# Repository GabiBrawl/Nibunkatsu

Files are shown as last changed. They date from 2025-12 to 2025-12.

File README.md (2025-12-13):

# Nibunkatsu One ✦ にぶんかつ
### A Split Mechanical Keyboard Built with Hack Club Blueprint

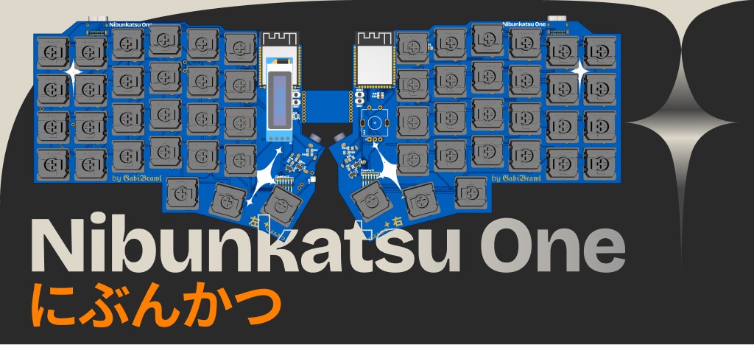
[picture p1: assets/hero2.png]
Nibunkatsu One


> にぶんかつ ✦ Nibunkatsu comes from the Japanese word for splitting in half.

Nibunkatsu is a compact split keyboard for typing and programming. I'll be using the ESP32-S3 microcontroller with KMK firmware, featuring RGB under the keys, an OLED display on the left half, and a rotary encoder in the right half!!

This project was created as part of the [Hack Club Blueprint](https://blueprint.hackclub.com) program that empowers high school students to design and build real hardware projects.

**Project Stats:** ~70 hours over the course of 1 week of active work and learning!

---

## Features

- **Split Design** — 5x7 layout per half, including a number row
- **RGB Underglow** — 28 individually addressable WS2812C LEDs per half
- **OLED Display** — 0.91" display for layer status and other keyboard info
- **Rotary Encoder** — PEC11 encoder for volume control and maybe more?
- **Hotswap Sockets** — Simple switch replacement without constant soldering
- **KMK Firmware** — Programmable using Python
- **TRRS Connection** — A 3.5mm audio cable for split communication between both halves. Also with ESD protection, protecting the MCU's TX/RX pins.

## Repository Structure

```
├── firmware/     - KMK firmware code and configuration
├── PCB/          - EasyEDA PCB project files and schematics
├── CAD/          - 3D models for the keyboard case and plates (.3mf and .step)
└── assets/       - Work screenshots and photos 
├── bom.csv       - Bill of Materials with supplier links, prices and quantities
```

---

## Hardware Specifications

### Core Components
- **Microcontroller:** ESP32-S3-WROOM-1-N4R2
- **Switches:** Cherry MX compatible hotswap sockets (I'll be personally using Gateron Banana low profile switches)
- **RGB LEDs:** WS2812C-2020
- **Display:** 0.91" OLED (128×32 pixels)
- **Encoder:** PEC11 rotary encoder with 24 steps and push button
- **Connection:** TRRS cable for communication between halves

### Case & Mounting
The case was designed in Shapr3D with 4 printable models:
- Left case + Left plate
- Right case + Right plate

Bo th available in `.3mf` and `.step` formats positioned in the [`CAD/`](CAD/) directory!

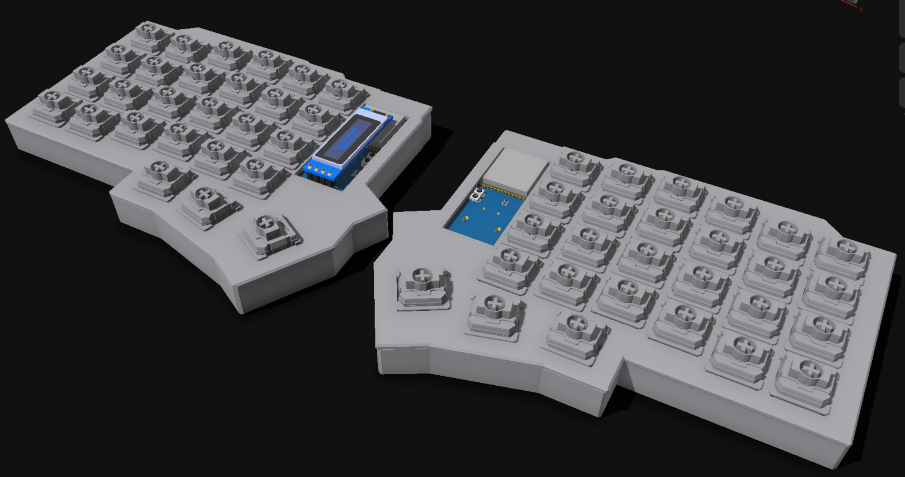
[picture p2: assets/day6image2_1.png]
3D Case Model


---

## Keymap

3-layer configuration:

- **Layer 0 (Base):** QWERTY layout with a number row
- **Layer 1 (Shortcuts):** Some operating system shortcuts maybe
- **Layer 2 (Navigation):** Arrow keys and media controls

## Firmware

Written in Python using the [KMK firmware framework](https://github.com/KMKfw/kmk_firmware).

The firmware source code is available in [`firmware/`](firmware/).

---

## Bill of Materials

**Total cost:** €153.11

| Component Type | Part Name | Qty | Other Notes |
| :--- | :--- | :--- | :--- |
| **Microcontroller** | ESP32-S3-WROOM-1-N4R2 | 3 | MCU |
| **Switches** | Gateron Low Profile (Banana) | 54 | Tactile yet silent |
| **Keycaps** | PBT Low Profile | 1 | Double-shot PBT, getting shine-through letters |
| **PCB Fabrication** | Custom PCB | 5 | via JLCPCB |
| **RGB LEDs** | WS2812C-2020 | 55 | Per-key RGB underglow |
| **Connectivity** | TRRS Cable | 1 | Interconnect cable |
| **Sockets** | Kailh Hot-Swap Sockets | 100 | Solder-free switch replacement |
| **Display** | 0.91" OLED | 1 | 128×32 pixel status display |
| **Controls** | PEC11 Rotary Encoder | 1 | Volume control |
| **Misc Electronics** | Diodes, Capacitors, LDOs, Resistors | ~150 | Logic, power regulation, ESD protection |

The complete CSV with supplier links is available here: [`bom.csv`](bom.csv)

---

## License

This project uses a three-part licensing model to appropriately protect hardware, software, and documentation.

| Component | License | Covers |
| :--- | :--- | :--- |
| **Hardware** | [CERN-OHL-W-2.0](LICENSE-hardware) | PCB designs, schematics, mechanical CAD files |
| **Firmware** | [MIT License](LICENSE-firmware) | Python/KMK firmware and source code |
| **Documentation** | [CC BY-SA 4.0](LICENSE-assets) | Assets, photos, diagrams, written guides |

### Why Three Licenses?

- **Hardware (CERN OHL):** Covers physical manufacturing rights and ensures attribution for derivative designs
- **Firmware (MIT):** Permissive software license allowing easy reuse and integration
- **Assets (CC BY-SA):** Ensures proper attribution for media assets and documentation

> **Note:** Third-party project dependencies may have different licenses. Please refer to their respective repositories for licensing information.

---

## Acknowledgments

Designed with 💙 by 𝕲𝕭

Special thanks to the Hack Club community for their support!

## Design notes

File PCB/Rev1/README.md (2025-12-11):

# Revision 1
This is the first revision of the PCB design for Nibunkatsu One.

You can check the [Schematic PDF here](./other%20assets/Nibunkatsu_One_Rev1_Schematics.pdf), and the [PCB PDF here](./other%20assets/Nibunkatsu_One_Rev1_PCB.pdf).

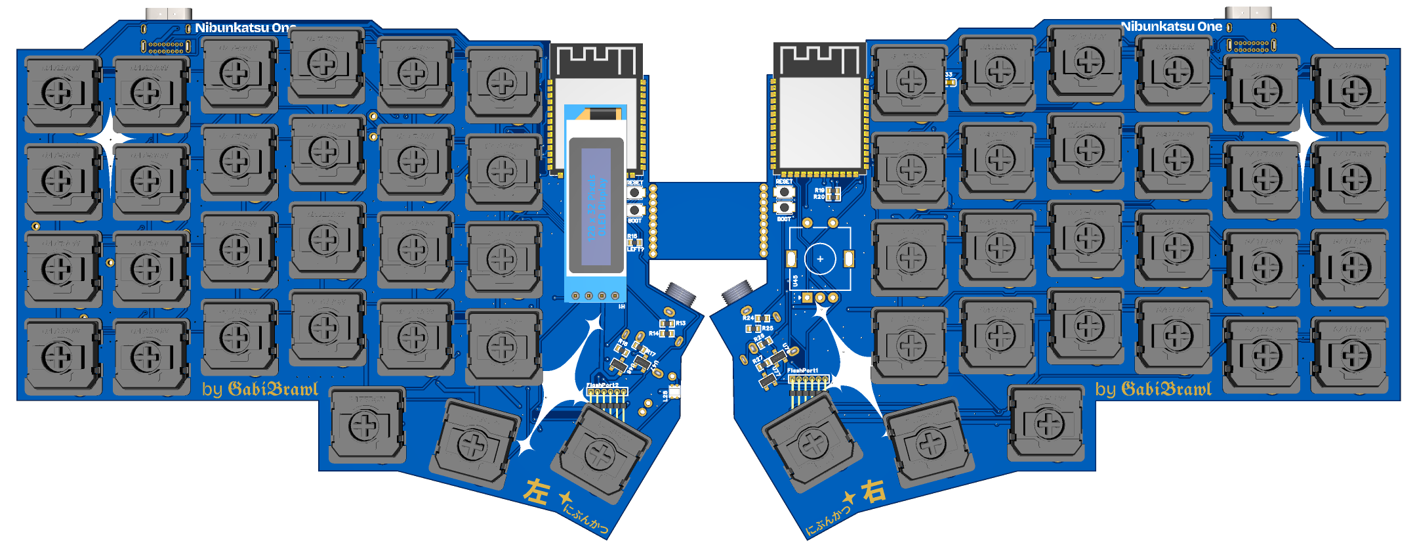
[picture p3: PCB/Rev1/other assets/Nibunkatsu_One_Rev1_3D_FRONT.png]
PCB Rev1 3D PCB Front

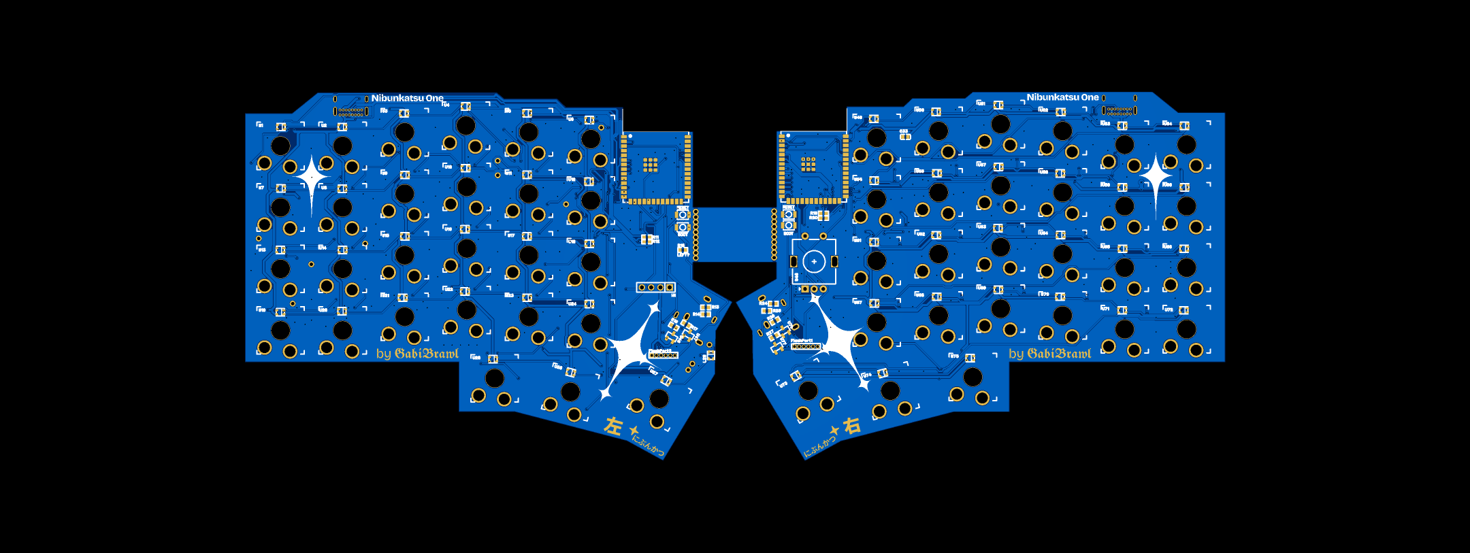
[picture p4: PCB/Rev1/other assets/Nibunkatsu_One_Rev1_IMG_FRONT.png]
PCB Rev1 PCB Front

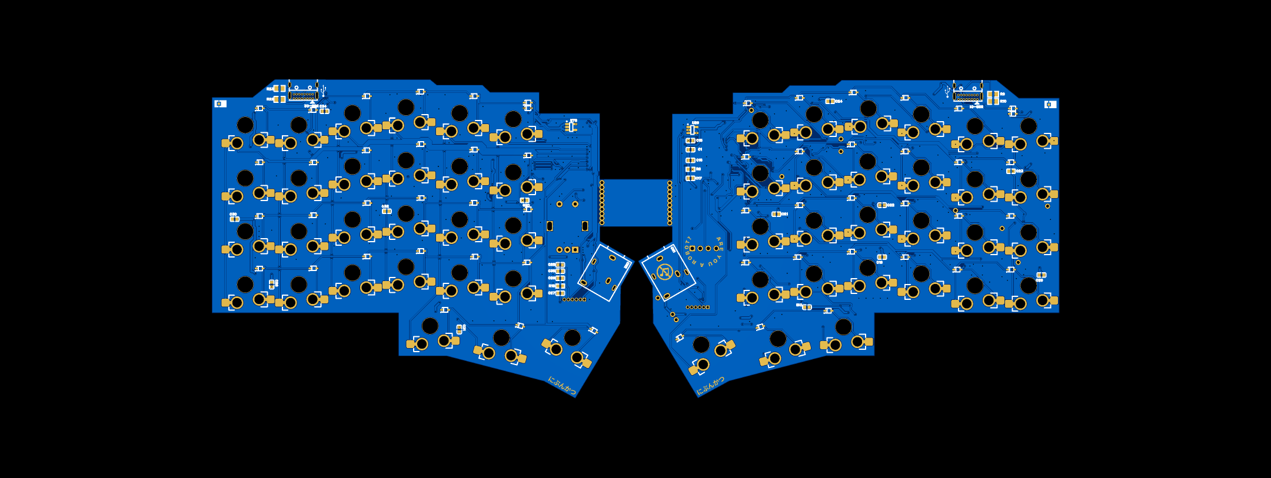
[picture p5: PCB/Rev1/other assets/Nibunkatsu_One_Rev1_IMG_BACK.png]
PCB Rev1 PCB Back


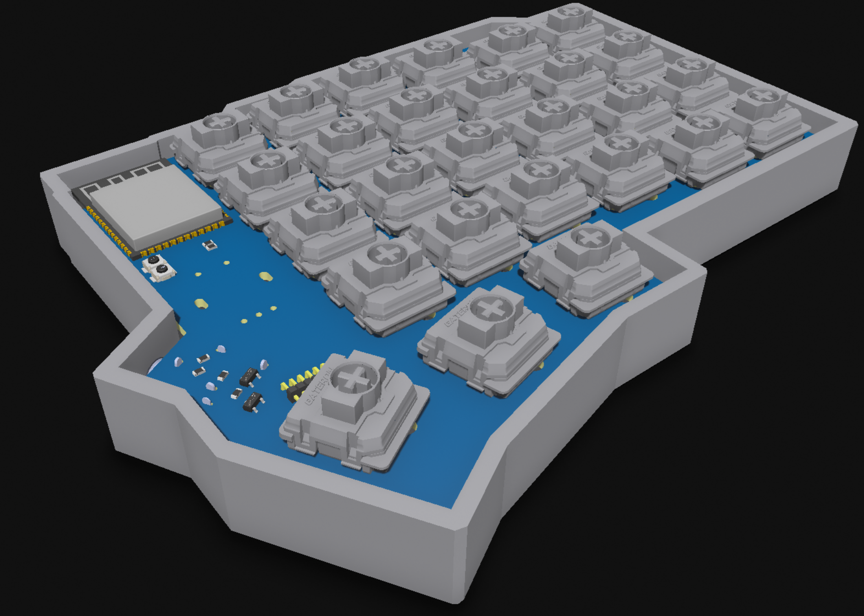
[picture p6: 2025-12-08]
assets/day5image6.png

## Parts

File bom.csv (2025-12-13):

Component Type | Comment | Quantity | Manufacturer Part | Unit Cost (Cost) | Total Cost (Cost)
MCU | ESP32-S3-WROOM-1-N4R2 | 3 | ESP32-S3-WROOM-1-N4R2 | 4.37 | 13.11 | https://www.digikey.pt/en/products/detail/espressif-systems/ESP32-S3-WROOM-1-N4/16162639
LED/Lighting | WS2812C-2020 | 55 | WS2812C-2020 | 0.15 | 11.61 | https://pt.aliexpress.com/item/32878302621.html
Diode | 1N4148WS | 60 | 1N4148WS | 0.057 | 3.42 | https://www.digikey.pt/en/products/detail/onsemi/1N4148WS/1873805
Diode | BAT54S | 5 | BAT54S | 0.11 | 0.55 | https://www.digikey.pt/en/products/detail/diotec-semiconductor/BAT54S/13164121
Switch | SW_Gateron_LowProfile_HotSwap_PTH1 | 54 | N/A | 0.4 | 31 | https://www.gateron.co/products/gateron-low-profile-mechanical-switch-set?variant=40557145784409
Switch | B3U-1000P | 5 | B3U-1000P | 0.81 | 4.05 | https://www.digikey.pt/en/products/detail/omron-electronics-inc-emc-div/B3U-1000P/1534338
Encoder | PEC11 | 1 | N/A | 1.9 | 1.9 | https://www.digikey.pt/en/products/detail/bourns-inc/PEC11R-4220F-S0024/4499660
Connector/Jack | PJ-324M | 2 | PJ-324M | 0.45 | 6.24 | https://pt.aliexpress.com/item/1005010212164993.html
Connector | USB4085-GF-A | 2 | USB4085-GF-A | 0.76 | 1.52 | https://www.digikey.pt/en/products/detail/gct/USB4085-GF-A/9859662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
Power Management | AP2112K-3.3TRG1 | 3 | AP2112K-3.3TRG1 | 0.35 | 1.05 | https://www.digikey.pt/en/products/detail/diodes-incorporated/AP2112K-3-3TRG1/4470746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
Capacitor | 1nF | 4 | N/A | 0.3 | 1.2 | https://www.digikey.pt/en/products/detail/kemet/C0603X102K5RAC3316/10315783
Capacitor | 1uF | 4 | N/A | 0.07 | 0.28 | https://www.digikey.pt/en/products/detail/samsung-electro-mechanics/CL10B105KP8NNNC/3887604
Capacitor | 0.1uF | 4 | N/A | 0.07 | 0.28 | https://www.digikey.pt/en/products/detail/kemet/C0603C104K5RACTU/1465594
Capacitor | 22uF | 4 | N/A | 0.07 | 0.28 | https://www.digikey.pt/en/products/detail/samsung-electro-mechanics/CL10A226MP8NUNE/3886932
Capacitor | 10uF | 8 | N/A | 0.07 | 0.56 | https://www.digikey.pt/en/products/detail/samsung-electro-mechanics/CL10A106KP8NNNC/3886850
Capacitor | 100nF | 20 | N/A | 0.125 | 2.5 | https://www.digikey.pt/en/products/detail/samsung-electro-mechanics/CL10E104KC8VPNC/20498486
Resistor | 10K | 8 | N/A | 0.09 | 0.72 | https://www.digikey.pt/en/products/detail/yageo/RC0603FR-0710KL/726880
Resistor | 22 | 8 | N/A | 0.12 | 0.96 | https://www.digikey.pt/en/products/detail/rohm-semiconductor/ESR03EZPJ220/1983463
Display | 0.91 inch oled white | 1 |  | 3.87 | 3.87 | https://pt.aliexpress.com/item/1005008918700196.html
Keycaps | MX Low Profile | 1 |  | 25.18 | 25.18 | https://pt.aliexpress.com/item/1005008279484599.html
Kailh Hotswap Sockets | 50 pack | 2 |  | 7.95 | 15.9 | https://splitkb.com/products/kailh-hotswap-sockets
TRRS Cable |  | 1 |  | 2.65 | 2.65 | https://pt.aliexpress.com/item/1005009181119614.html
3D Prints | 2 case sides of the keyboard and 2 plates | 1 |  |  | 0
PCB |  | 1 |  | 24.28 | 24.28
 |  |  |  | Grand Total: | 153.11

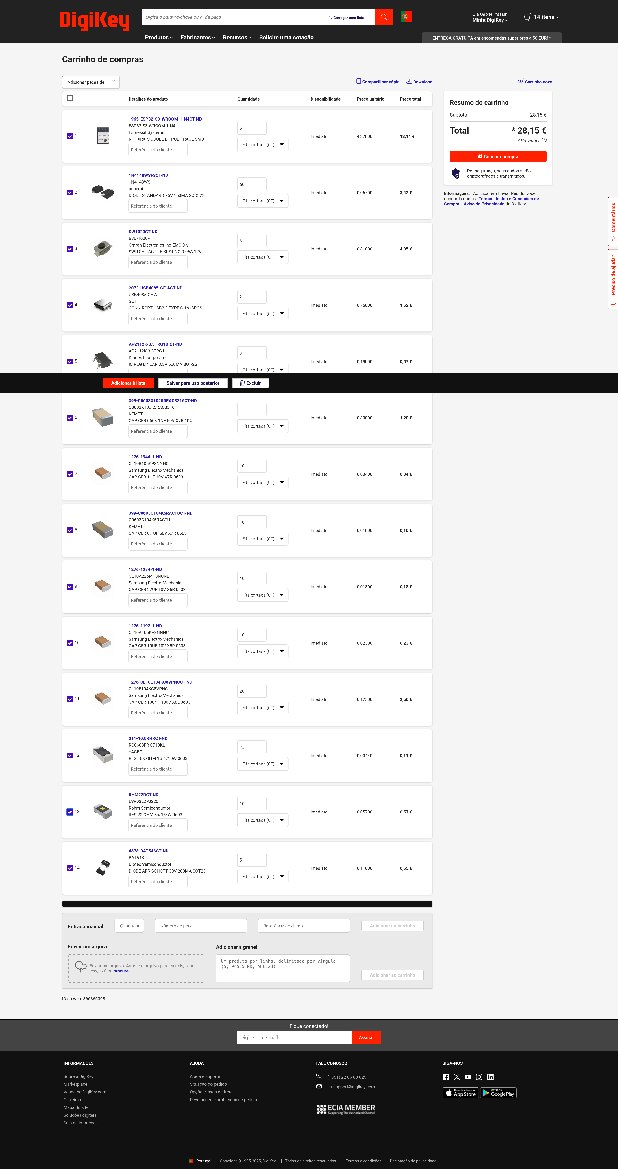
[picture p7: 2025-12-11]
assets/Shopping Cart Screenshots/DigiKey.png

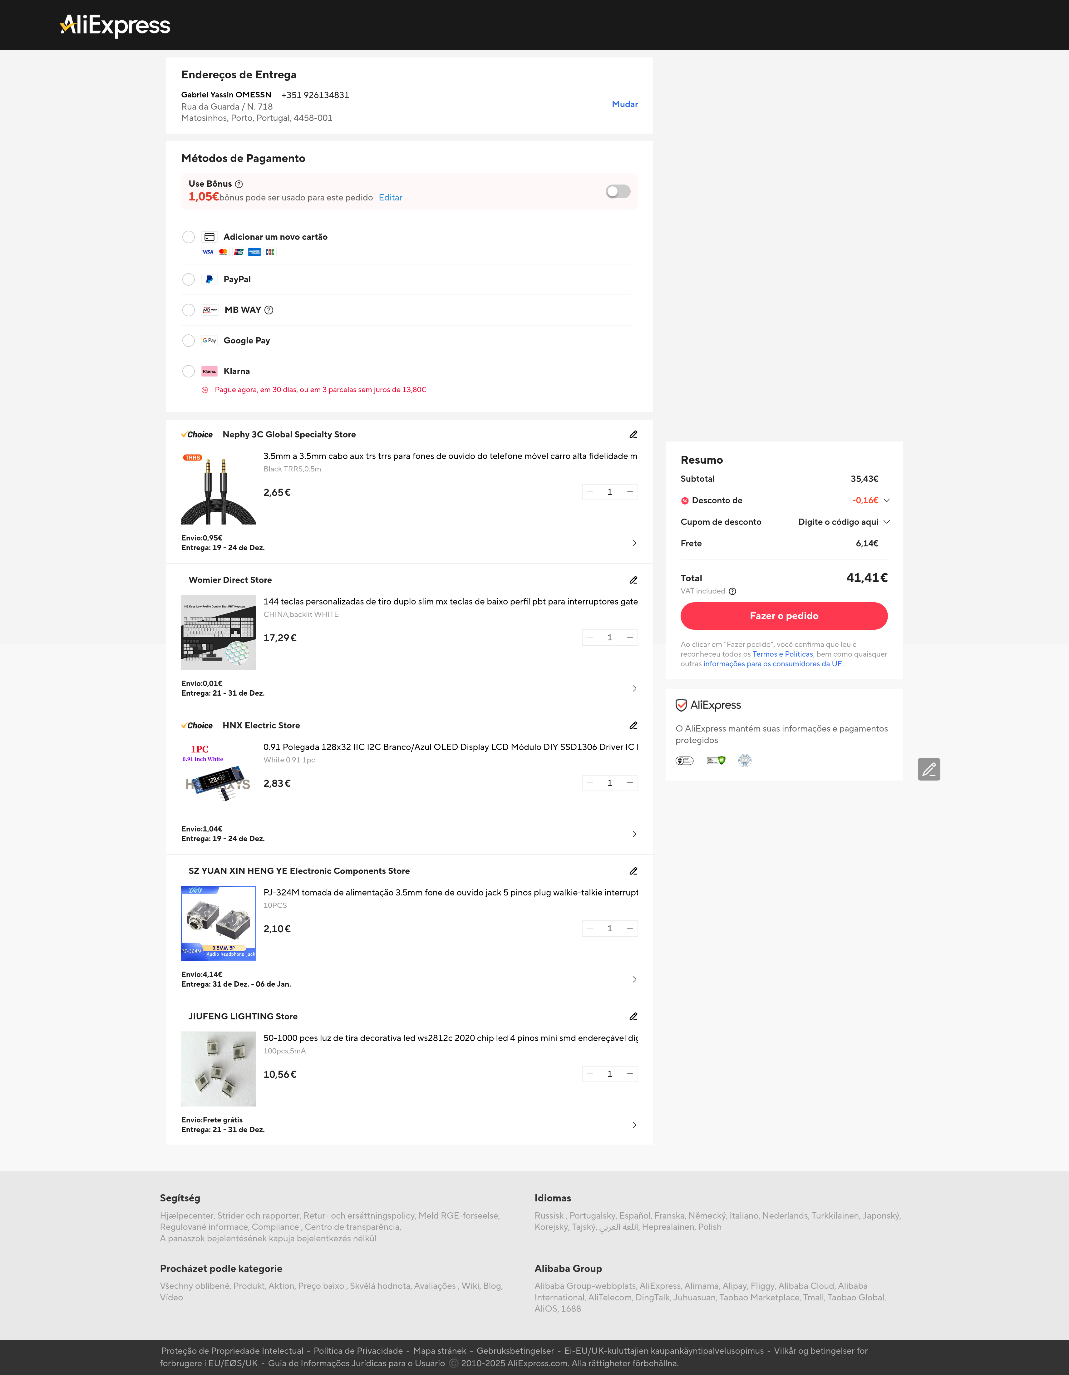
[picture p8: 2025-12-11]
assets/Shopping Cart Screenshots/AliExpress.png

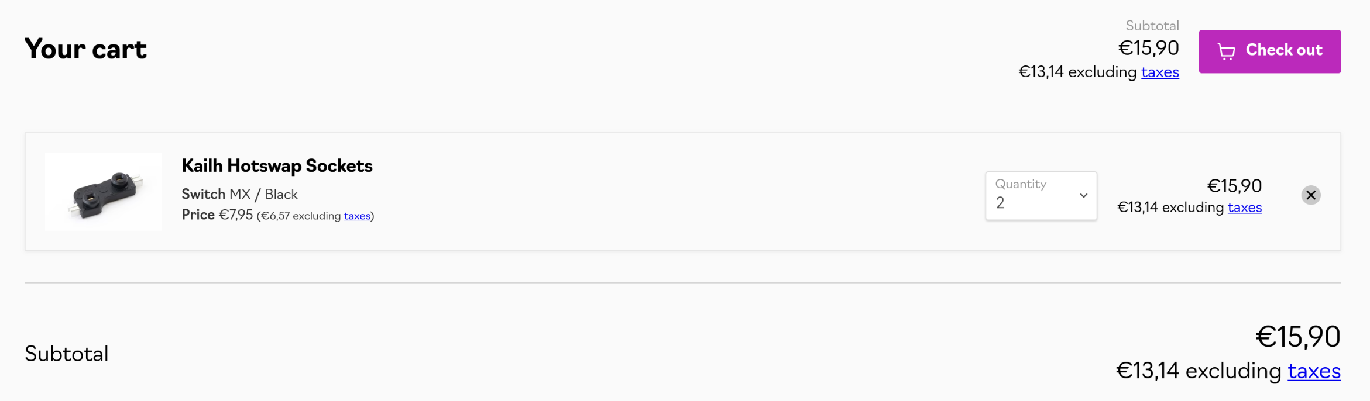
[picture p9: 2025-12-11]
assets/Shopping Cart Screenshots/Splitkb.png

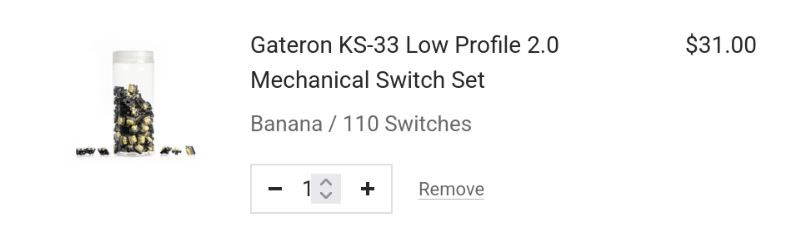
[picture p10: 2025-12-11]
assets/Shopping Cart Screenshots/Gateron.png

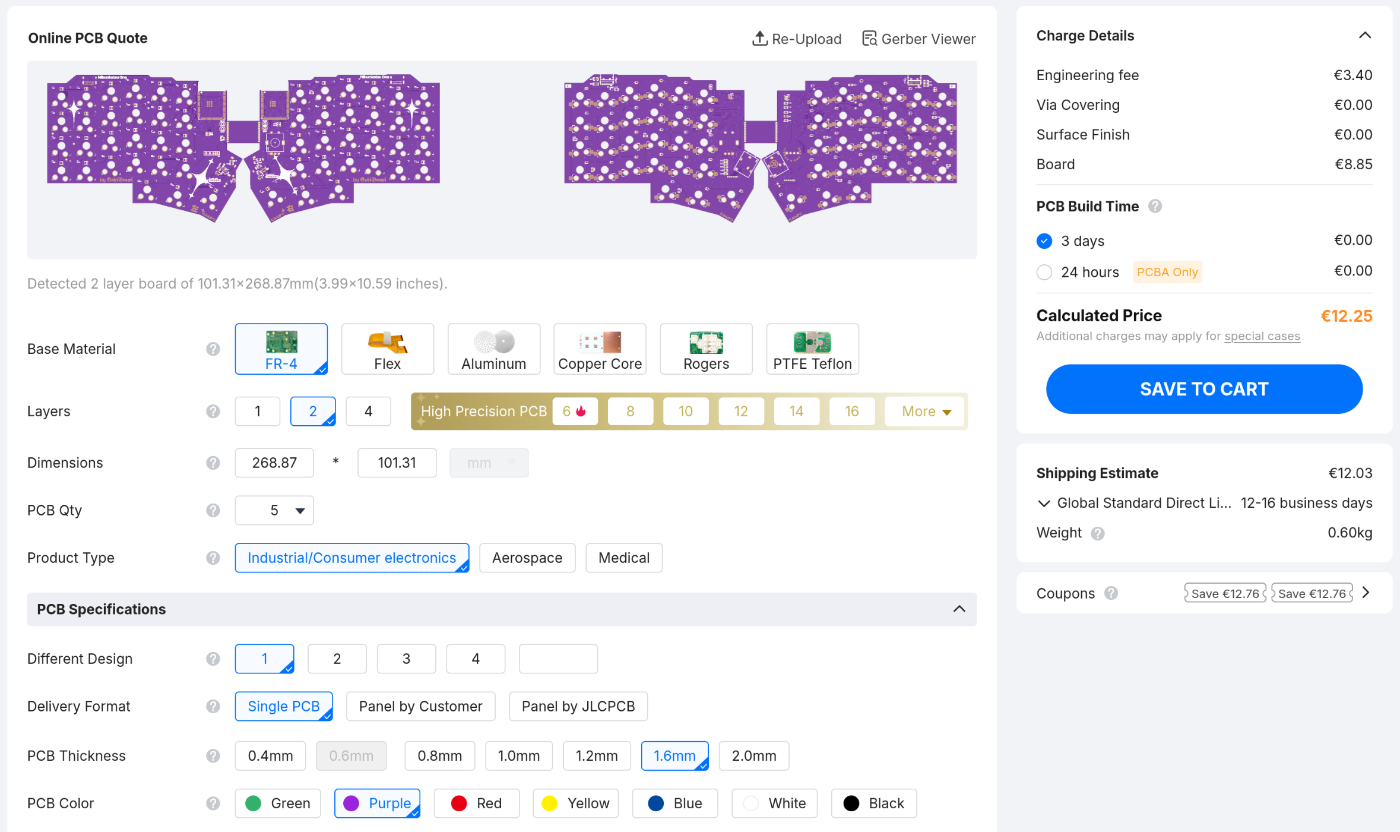
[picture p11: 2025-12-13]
assets/Shopping Cart Screenshots/JLCPCB.png

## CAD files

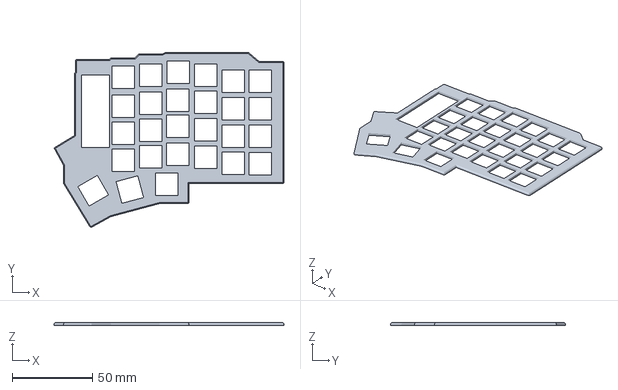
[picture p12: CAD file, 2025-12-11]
CAD/Nibunkatsu_One_PLATE_RIGHT.3mf
143.1 x 108.7 x 1.60 mm

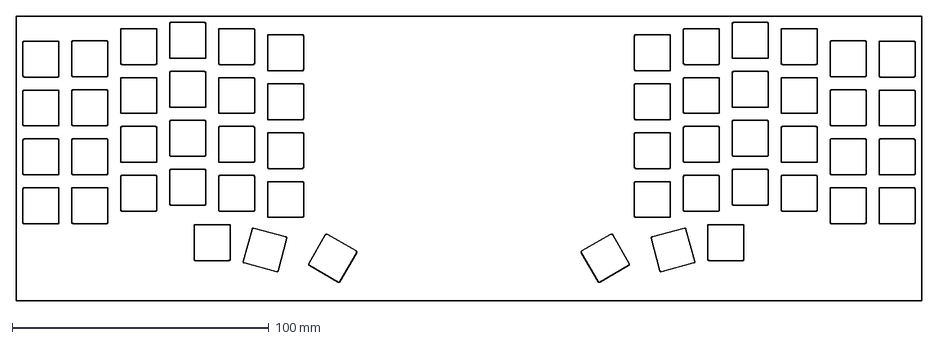
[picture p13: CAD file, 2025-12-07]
CAD/plate/revision1/plate-2025-12-07T15_16_46.762Z.dxf
352.4 x 111.0 mm

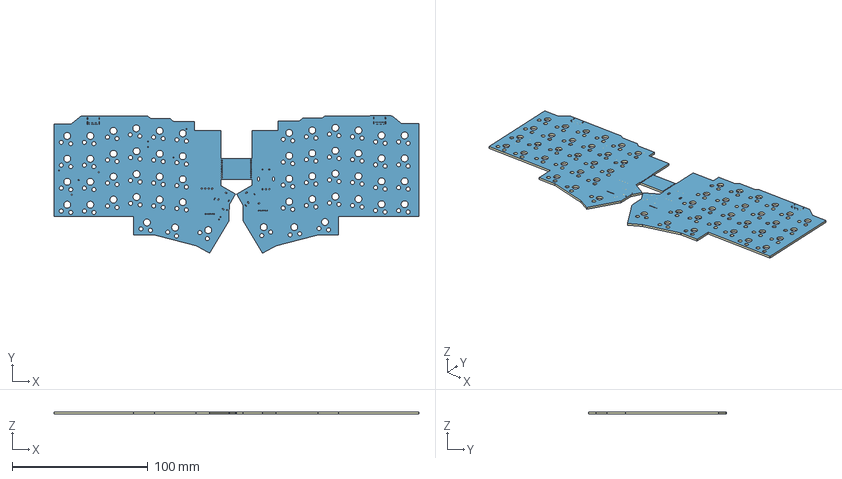
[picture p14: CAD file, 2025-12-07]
PCB/Rev1/Nibunkatsu_One_Rev1_3D_minimal.step
268.8 x 101.3 x 1.60 mm
dZRG-TopTrack
dZRG-BottomTrack
dZRG-Board
dZRG-Top FPC Stiffener
dZRG-Bot FPC Stiffener

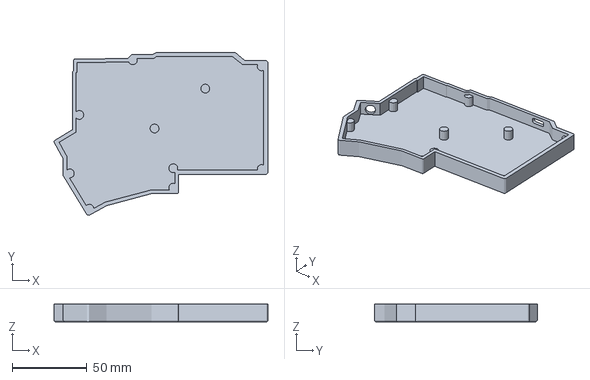
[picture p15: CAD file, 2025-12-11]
CAD/Nibunkatsu_One_CASE_RIGHT.3mf
142.8 x 108.5 x 12.0 mm

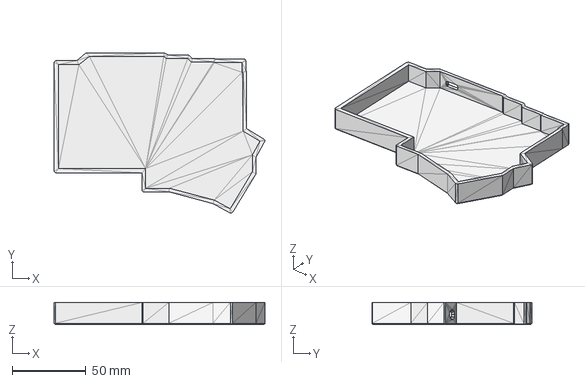
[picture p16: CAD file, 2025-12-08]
CAD/Nibunkatsu_One_Rev1_LEFT.step
142.8 x 108.5 x 15.0 mm

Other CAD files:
CAD/Nibunkatsu_One_PLATE_LEFT.3mf
CAD/Nibunkatsu_One_CASE_LEFT.3mf
CAD/Nibunkatsu_One_Rev1_RIGHT.step
CAD/Nibunkatsu_One_CASE_LEFT.obj
CAD/Nibunkatsu_One_CASE_RIGHT.obj
CAD/Nibunkatsu_One_PLATE_LEFT.obj
CAD/Nibunkatsu_One_PLATE_RIGHT.obj
CAD/Nibunkatsu_One_Rev1_LEFT.3mf
CAD/Nibunkatsu_One_Rev1_RIGHT.3mf

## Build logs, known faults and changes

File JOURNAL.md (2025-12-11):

## 12/03/2025 - Planning and Design

Started with initial keyboard layout design and component selection, alongside left-side schematics started and pcb design.

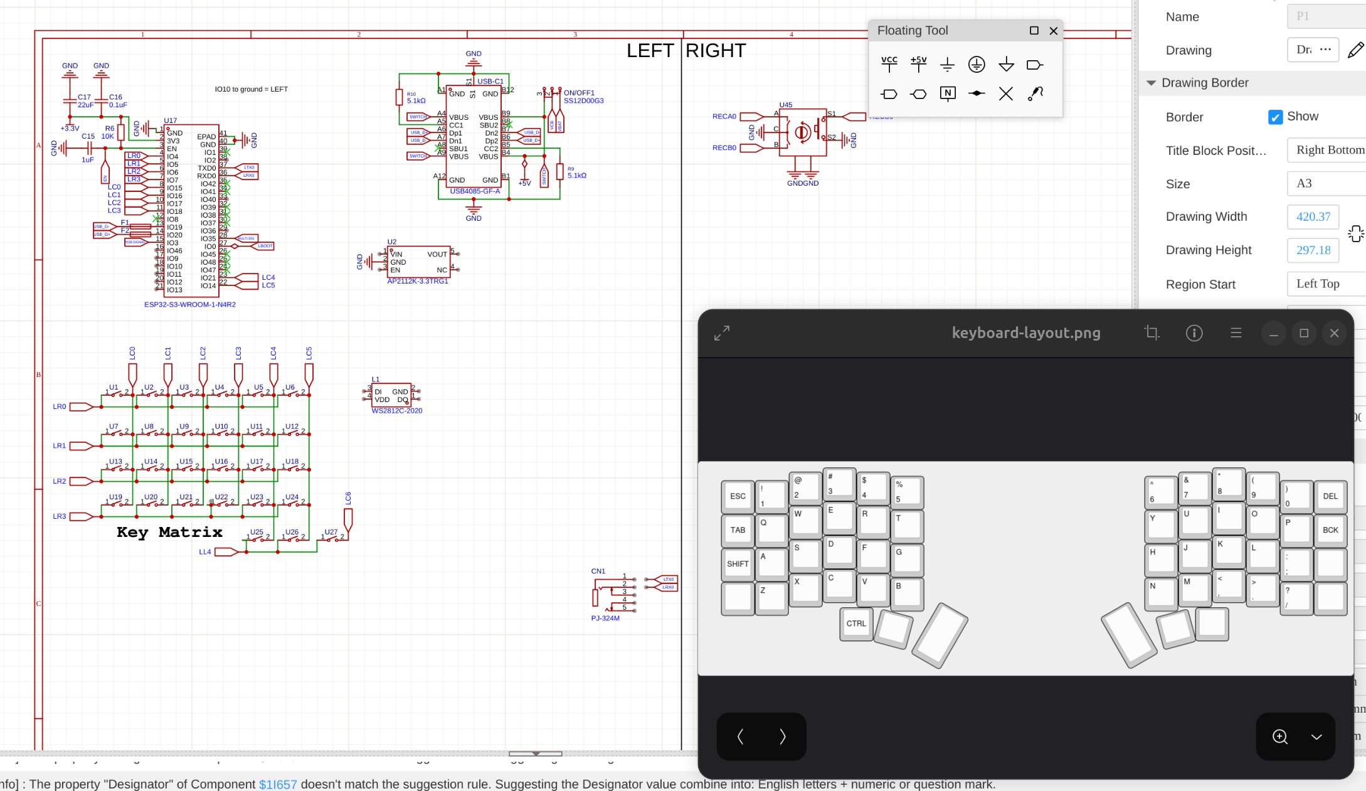
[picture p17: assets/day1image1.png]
Day 1 Image 1

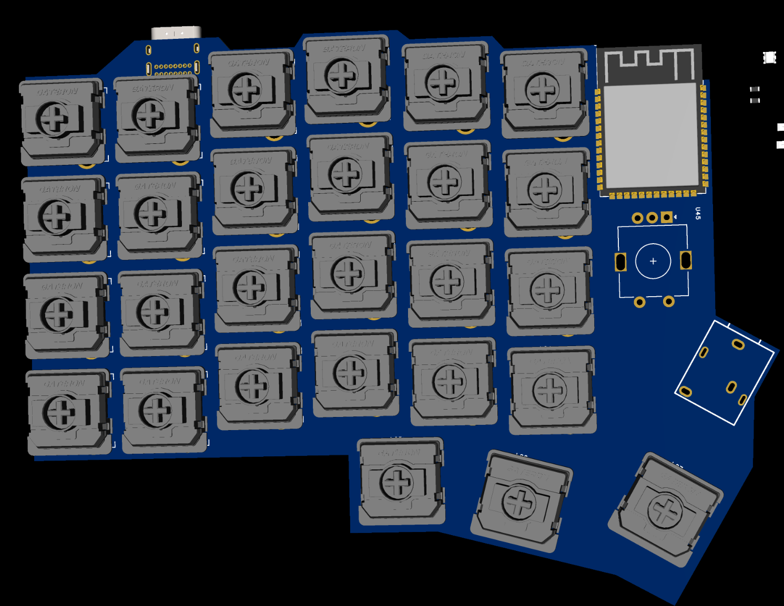
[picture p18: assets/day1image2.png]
Day 1 Image 2


## 12/04/2025 - More planning and design
Kept iterating with the pcb design and schematic, still on the left side only.

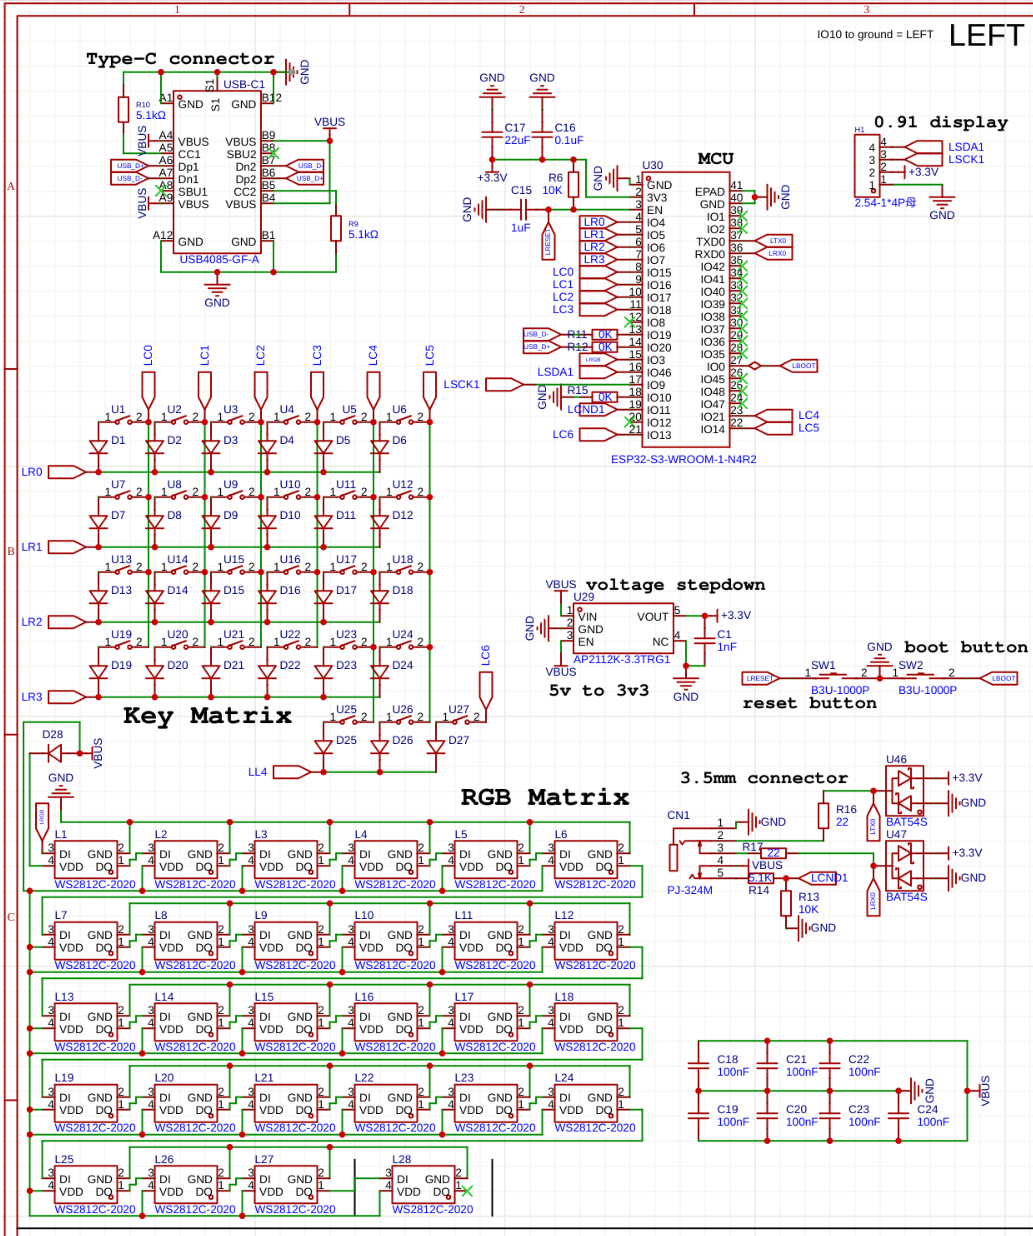
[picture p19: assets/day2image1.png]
Day 2 Image 1

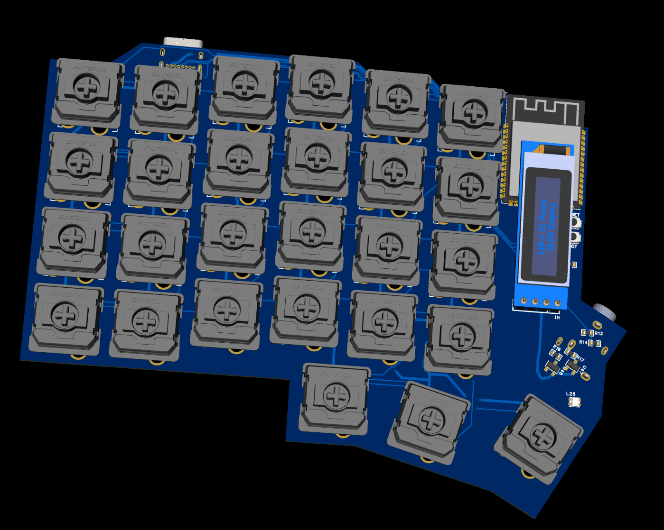
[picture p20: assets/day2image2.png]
Day 2 Image 2

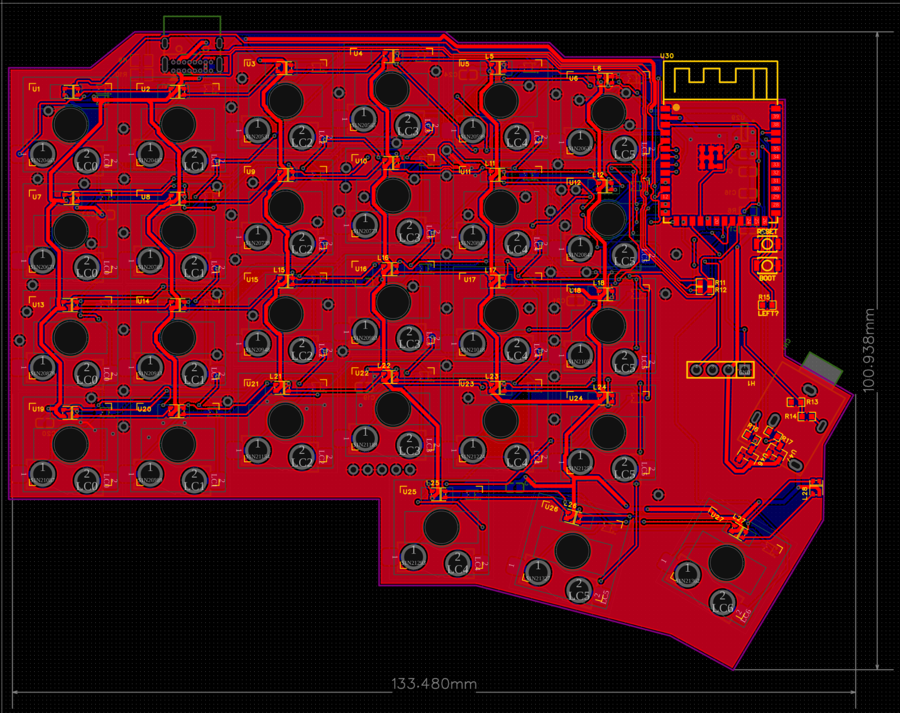
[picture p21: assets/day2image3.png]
Day 2 Image 3

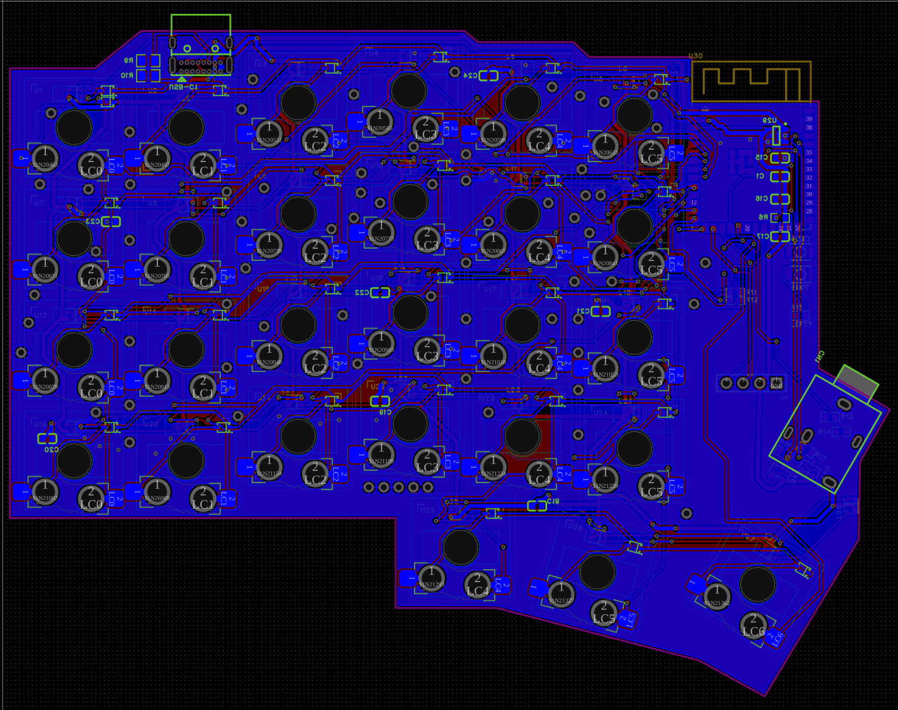
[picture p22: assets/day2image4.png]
Day 2 Image 4


## 12/05/2025 - Even more planning and design

Began working on the right side schematic and pcb design. Added custom artwork to the pcb.

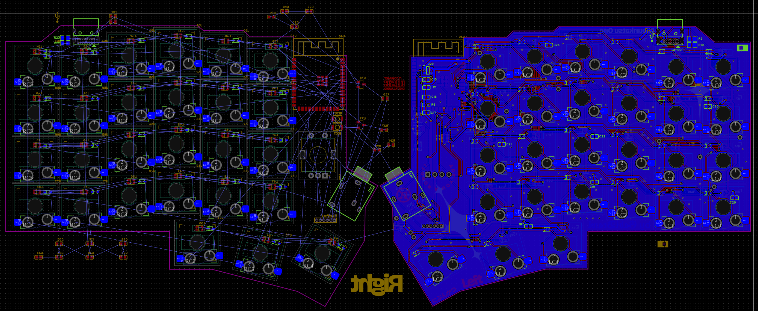
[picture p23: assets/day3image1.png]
Day 3 Image 1

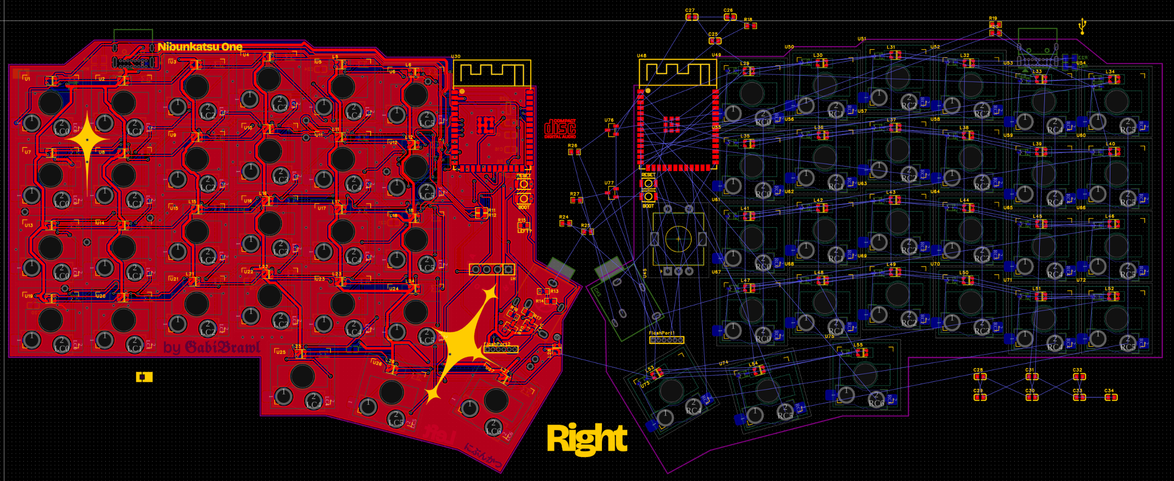
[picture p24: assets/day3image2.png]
Day 3 Image 2

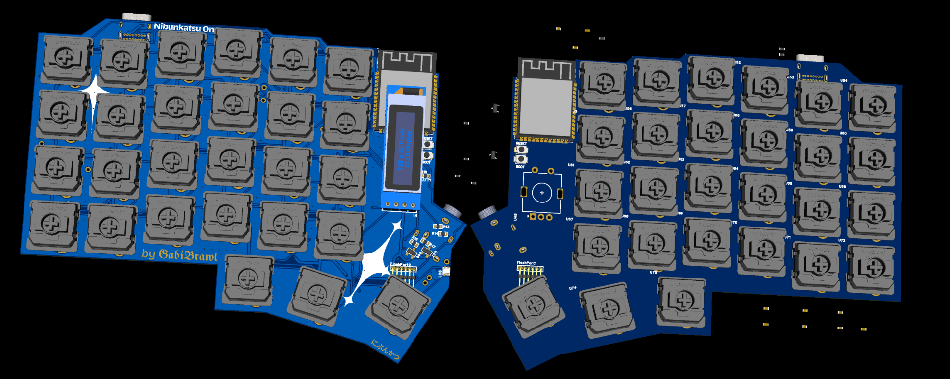
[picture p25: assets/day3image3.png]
Day 3 Image 3


## 12/06/2025 - Final PCB design

Finalized both sides of the schematic and pcb design. Prepared files for manufacturing.
Only on PCB planning and design I easily spent around 30 hours, in those 4 days.

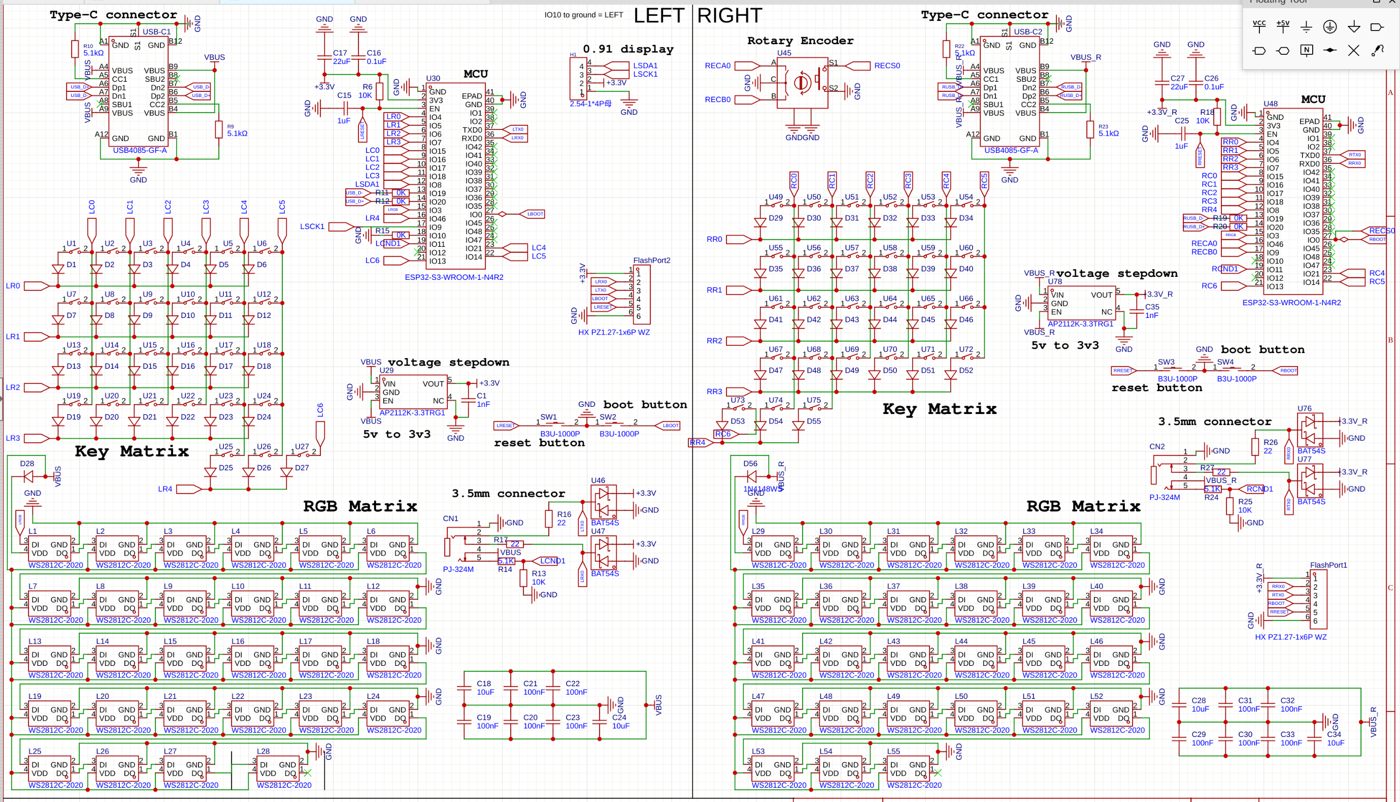
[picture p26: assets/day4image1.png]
Day 4 Image 1

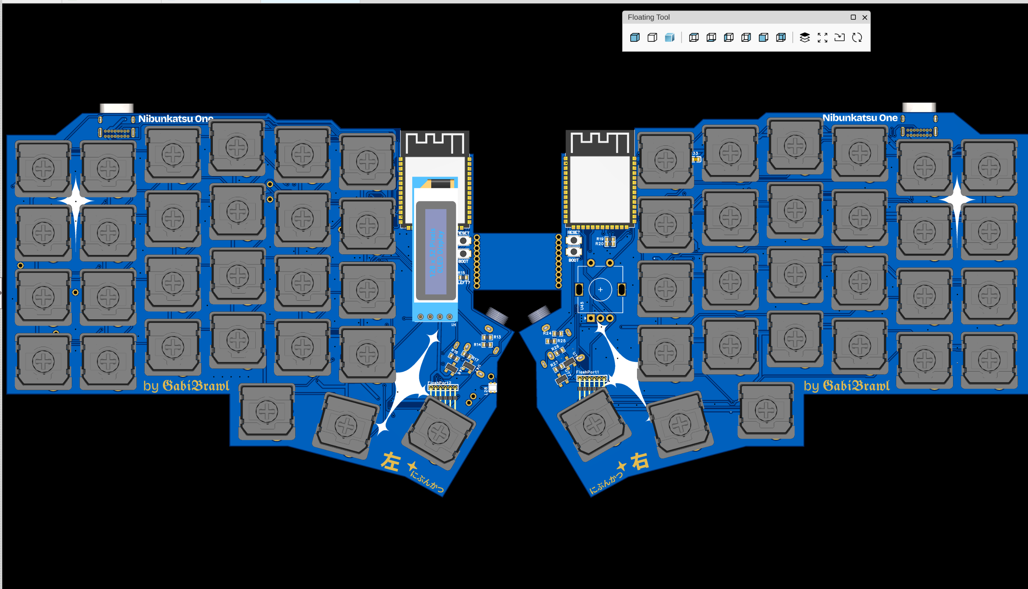
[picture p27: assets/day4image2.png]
Day 4 Image 2

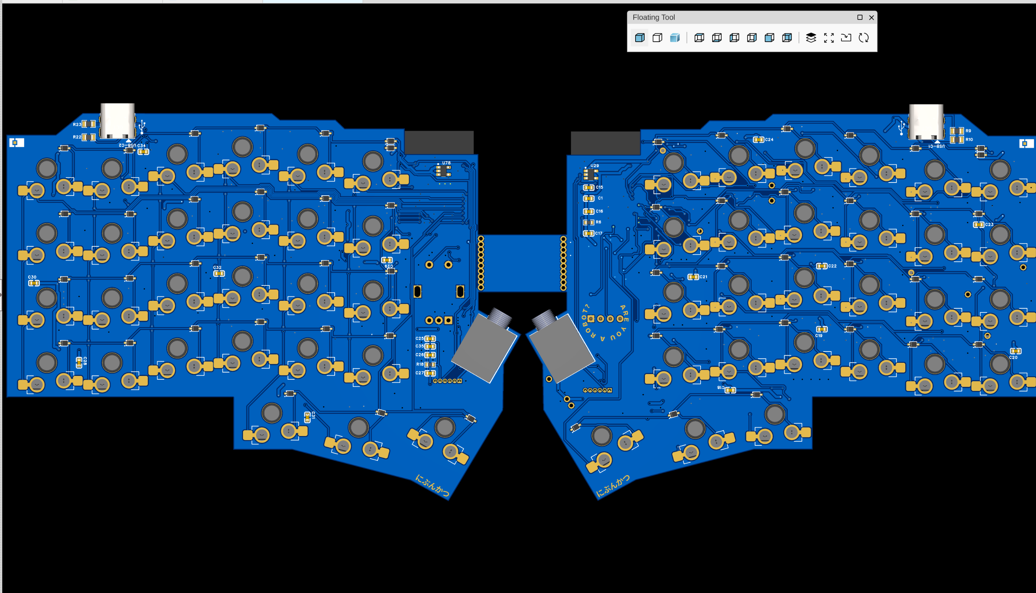
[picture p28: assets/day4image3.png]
Day 4 Image 3

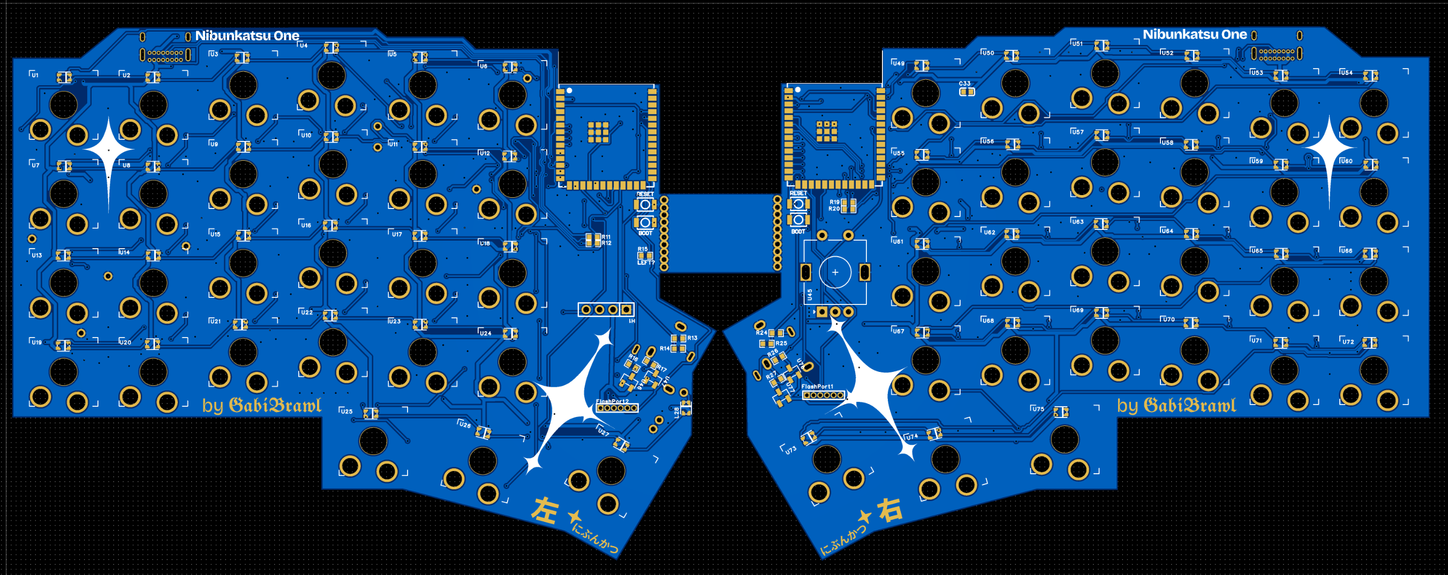
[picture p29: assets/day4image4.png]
Day 4 Image 4

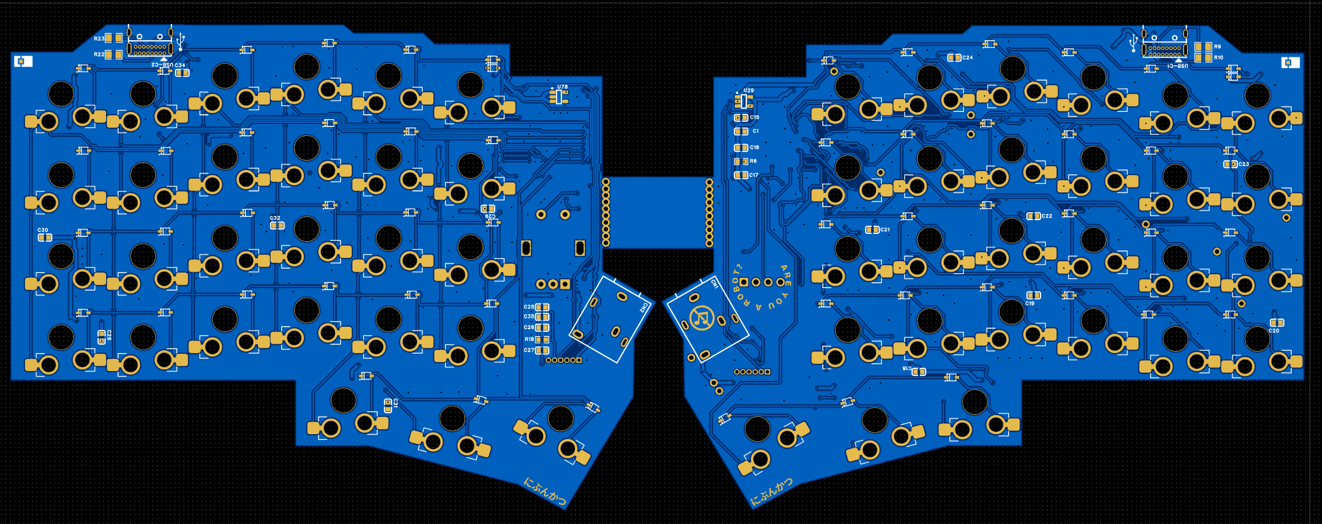
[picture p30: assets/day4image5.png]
Day 4 Image 5


## 12/08/2025 - 3D CAD Modeling

Made the 3D model for both sides of Nibunkatsu using Shapr3D! This is my first time modeling something in 3D, and I'm absolutely impressed by the result!! This is so much easier than I've ever expected it to be :D

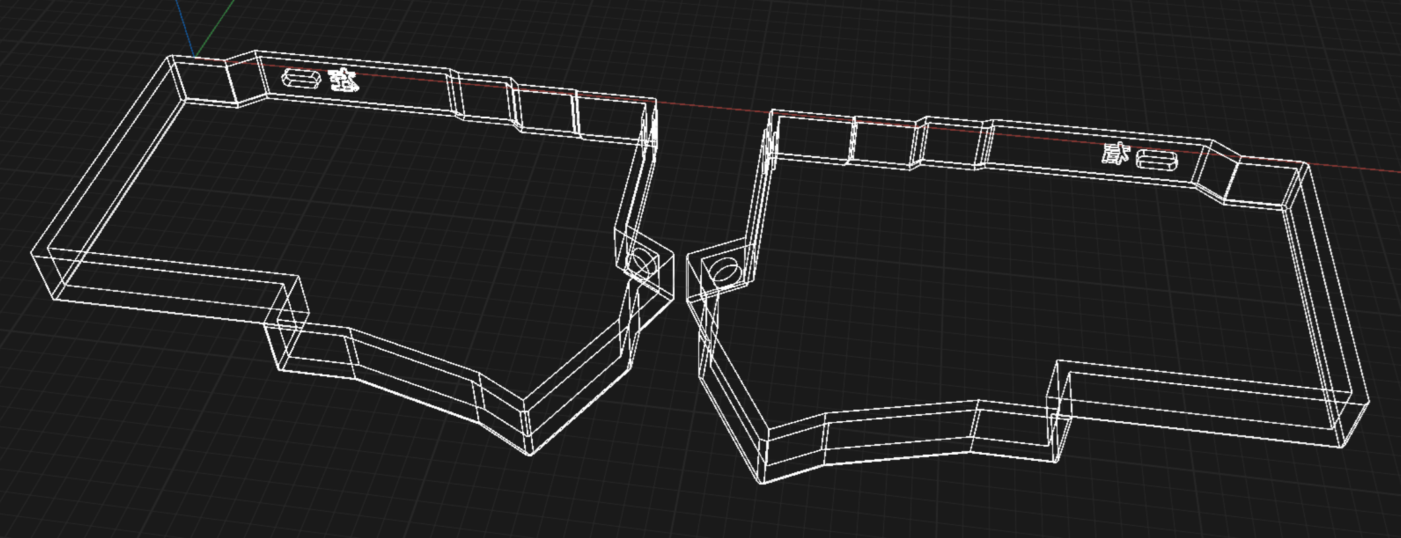
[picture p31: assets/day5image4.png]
Day 5 Image 4

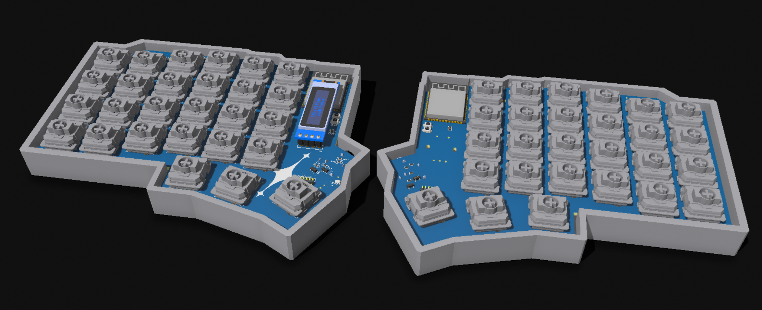
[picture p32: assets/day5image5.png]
Day 5 Image 5

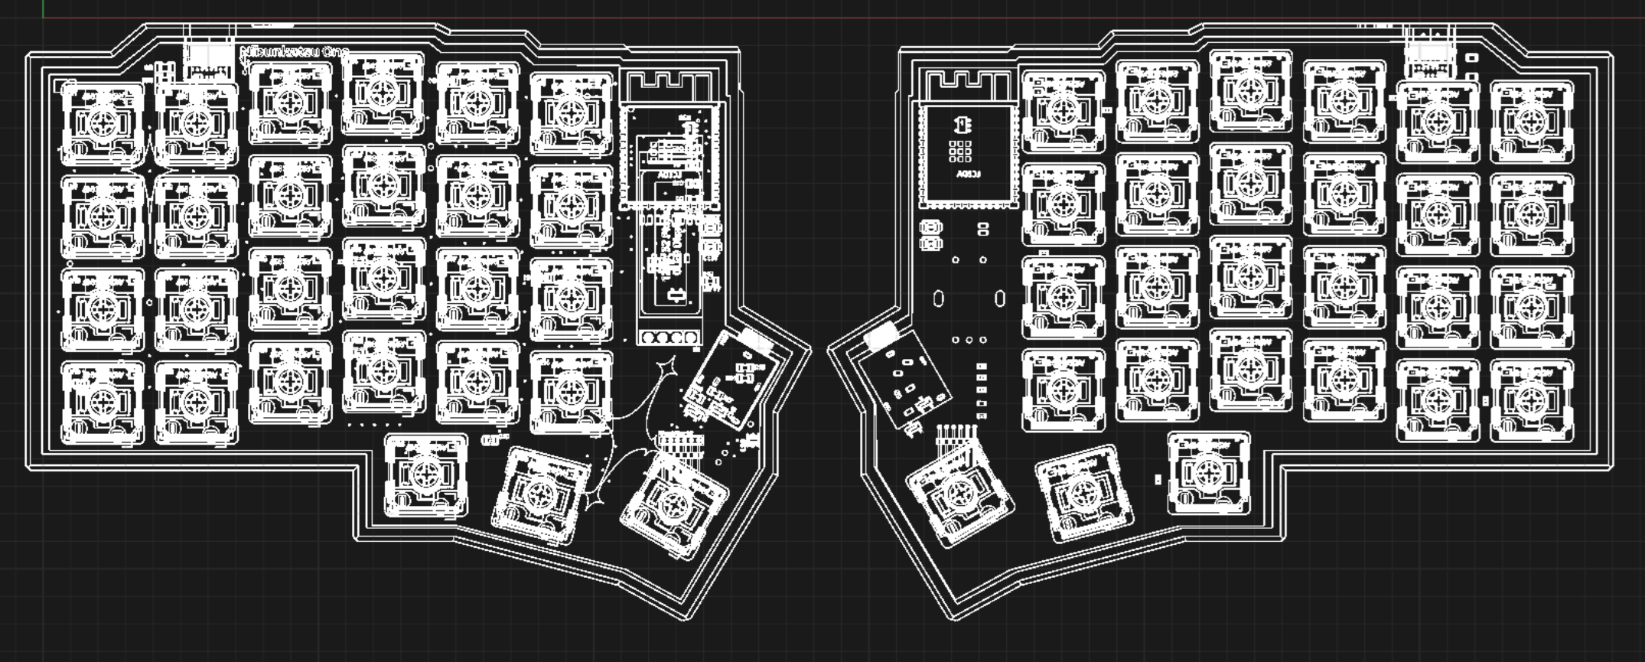
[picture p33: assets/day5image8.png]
Day 5 Image 8


## 12/10/2025 - 0.91 inch display UI design and testing

Made a sample UI design that fits the vertical layout of the 0.91 inch display, and tested it on an actual display module. I looked up online and didn't find anyone using this display in vertical orientation, so I had to improvise a bit. But it is turning out great! This is by no means the final, but gives a taste. :P
Everything was designed using lopaka.app, which is an amazing tool for making pixel art and small UIs for displays like this.

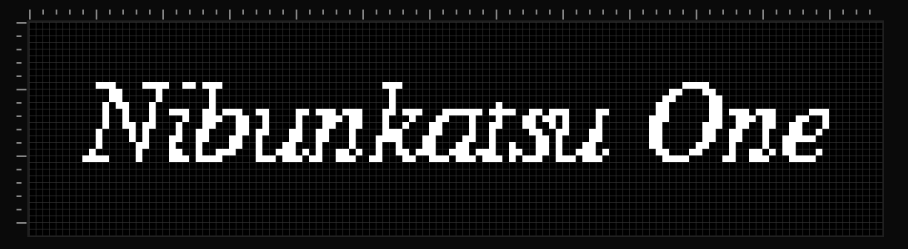
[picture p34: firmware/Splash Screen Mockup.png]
Display Image 1

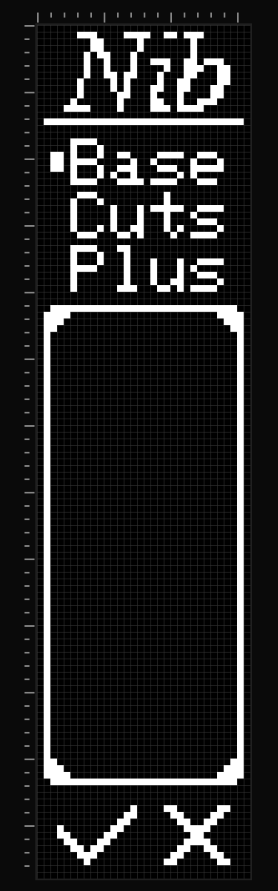
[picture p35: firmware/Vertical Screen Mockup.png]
Display Image 2


## 12/11/2025 - 3D Model Improvements
After procastinating for a while, I finally decided to improve on the 3D models more. Added support cilinders to hold the PCBs in the right height, and made the plates where the switches will be mounted on! Now there are 4 models to be printed: Left case, Right case, Left plate and Right plate.

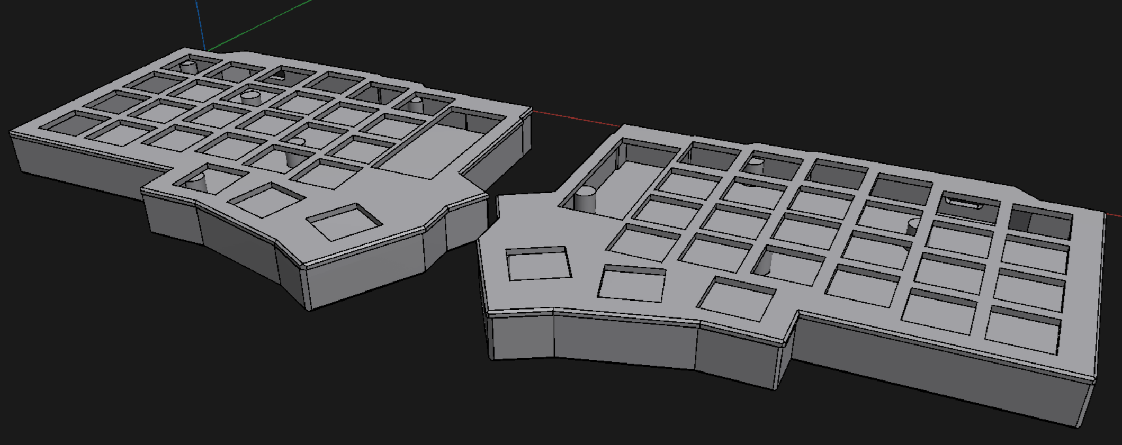
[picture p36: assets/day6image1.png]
Day 6 Image 1

Day 6 Image 2_1
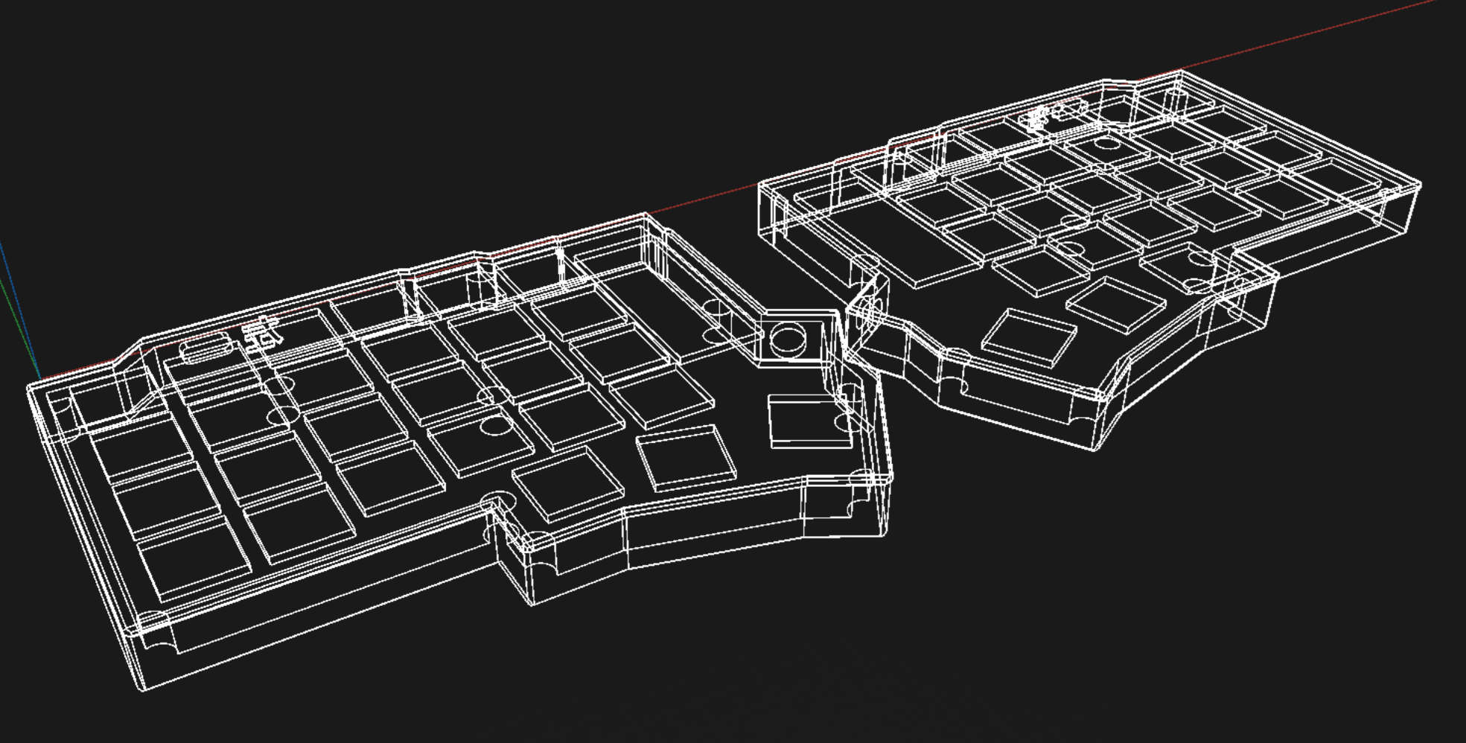
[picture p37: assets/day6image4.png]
Day 6 Image 4


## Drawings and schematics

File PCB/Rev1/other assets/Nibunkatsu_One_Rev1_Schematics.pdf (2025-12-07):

IO13 21 | IO14 22 IO21 23 IO47 24 IO48 25 IO45 26 IO0 27 IO35 28 IO36 29 IO37 30 IO38 31 IO39 32 IO40 33 IO41 34 IO42 35 RXD0 36 TXD0 37 IO2 38 IO1 39 GND 40 EPAD 41
GND | GNDLRESET

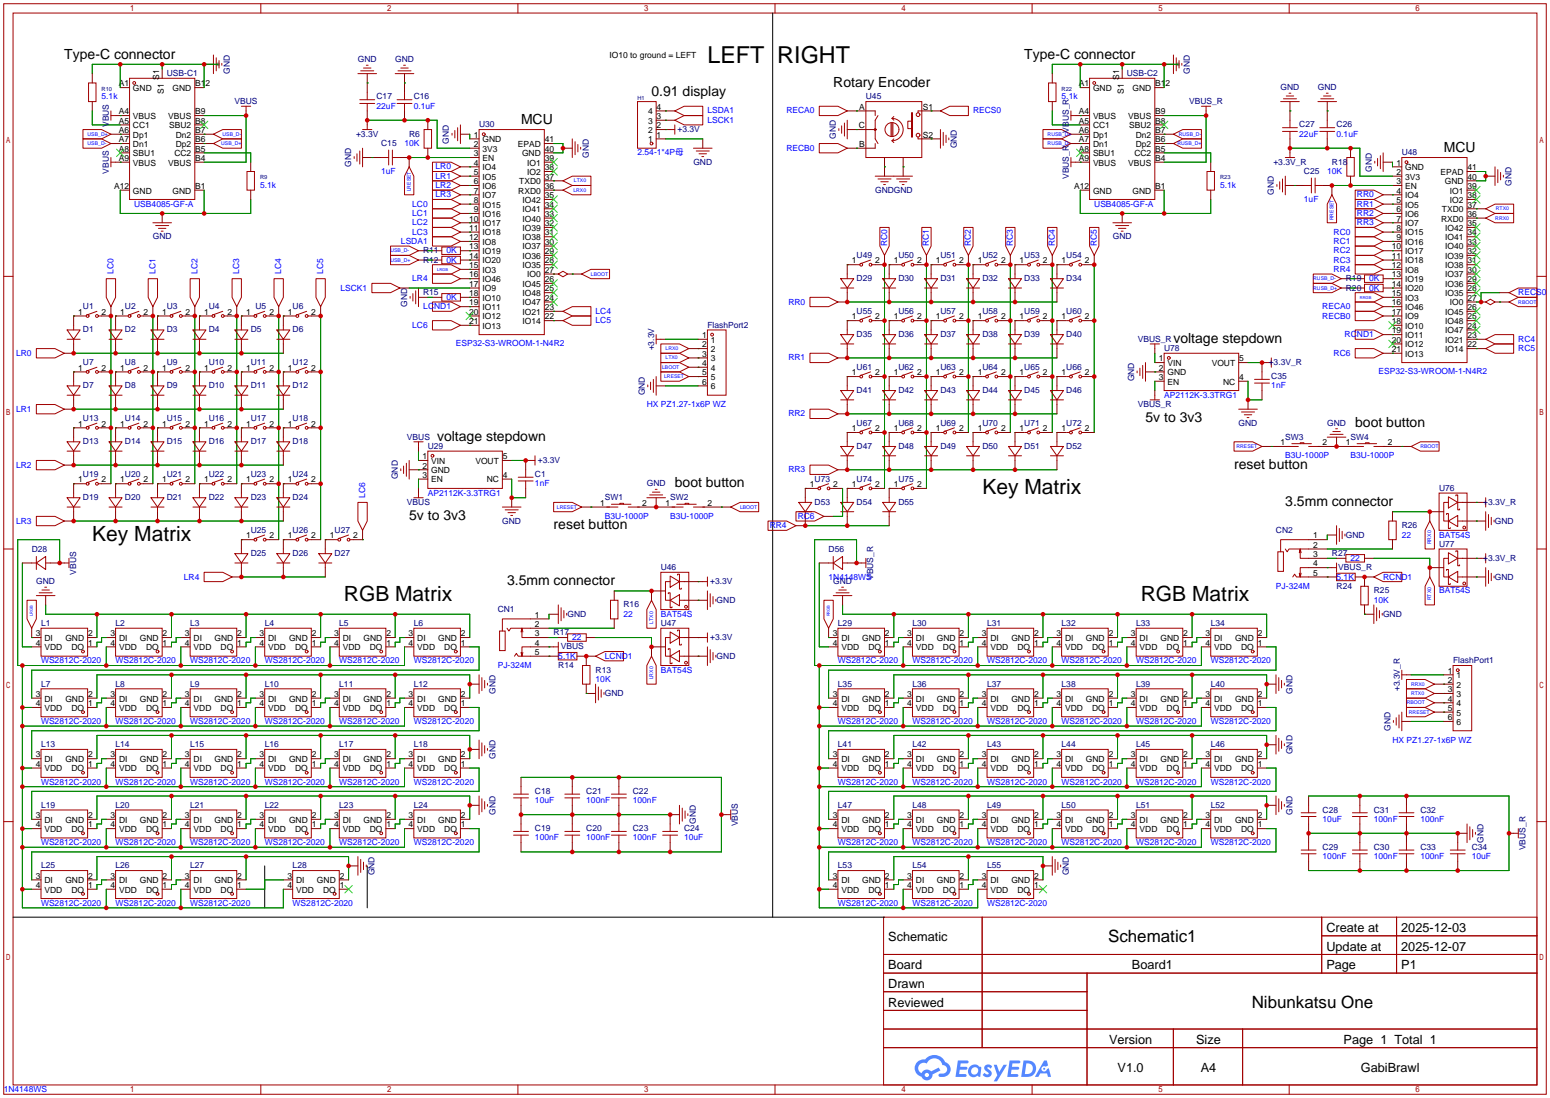
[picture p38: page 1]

Update at | 2025-12-07

Board | Board1 | Page | P1
Drawn | | Nibunkatsu One
Reviewed

Version | Size | Page 1 Total 1
V1.0 | A4 | GabiBrawl

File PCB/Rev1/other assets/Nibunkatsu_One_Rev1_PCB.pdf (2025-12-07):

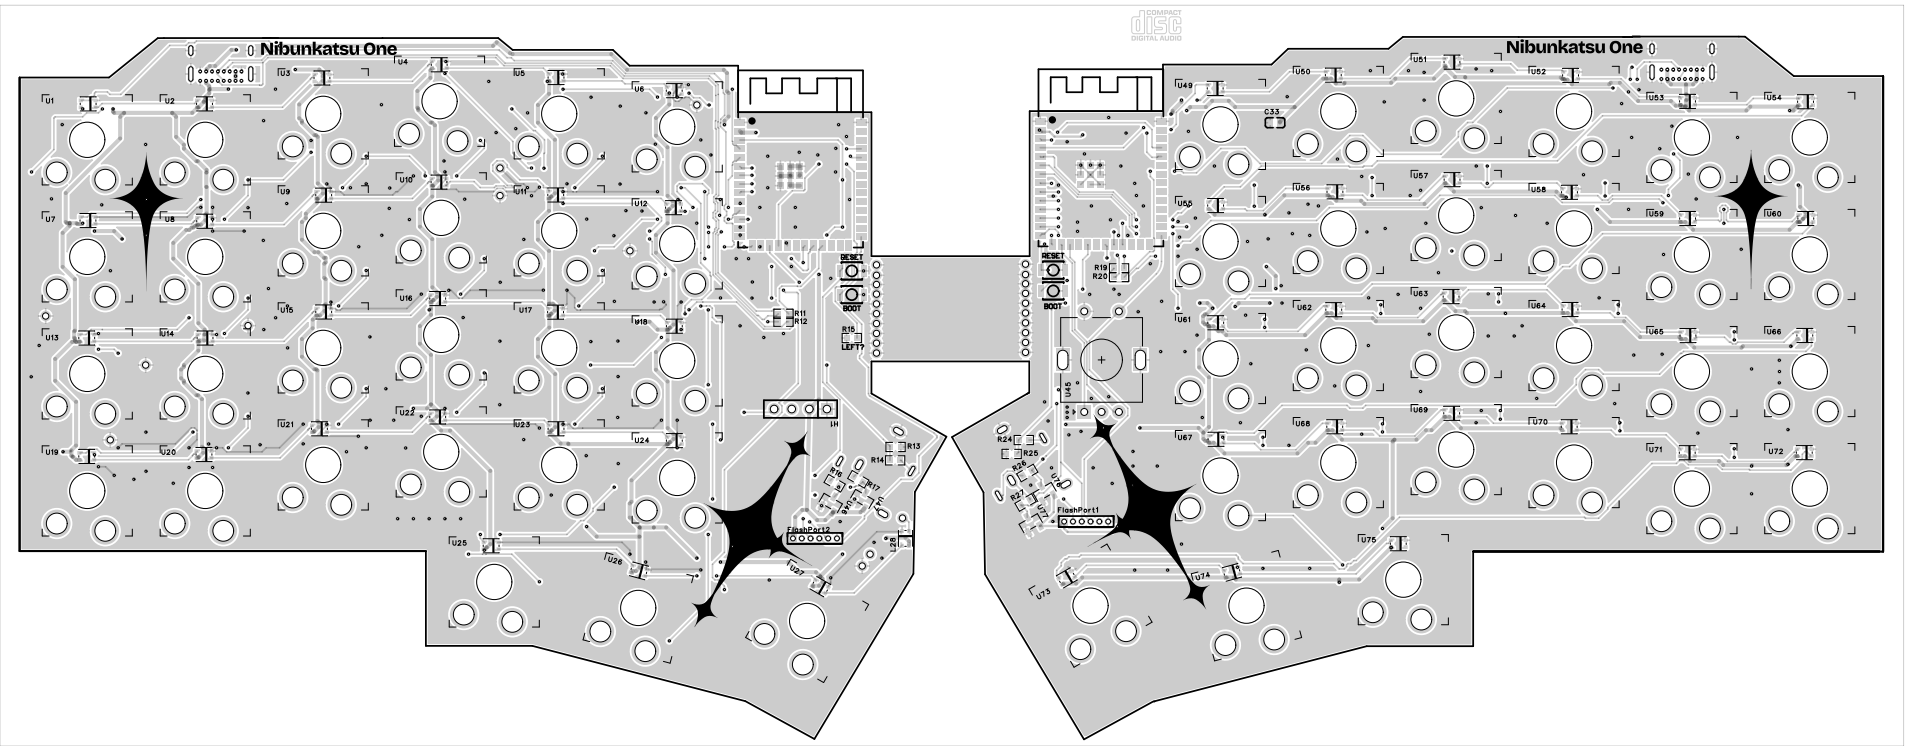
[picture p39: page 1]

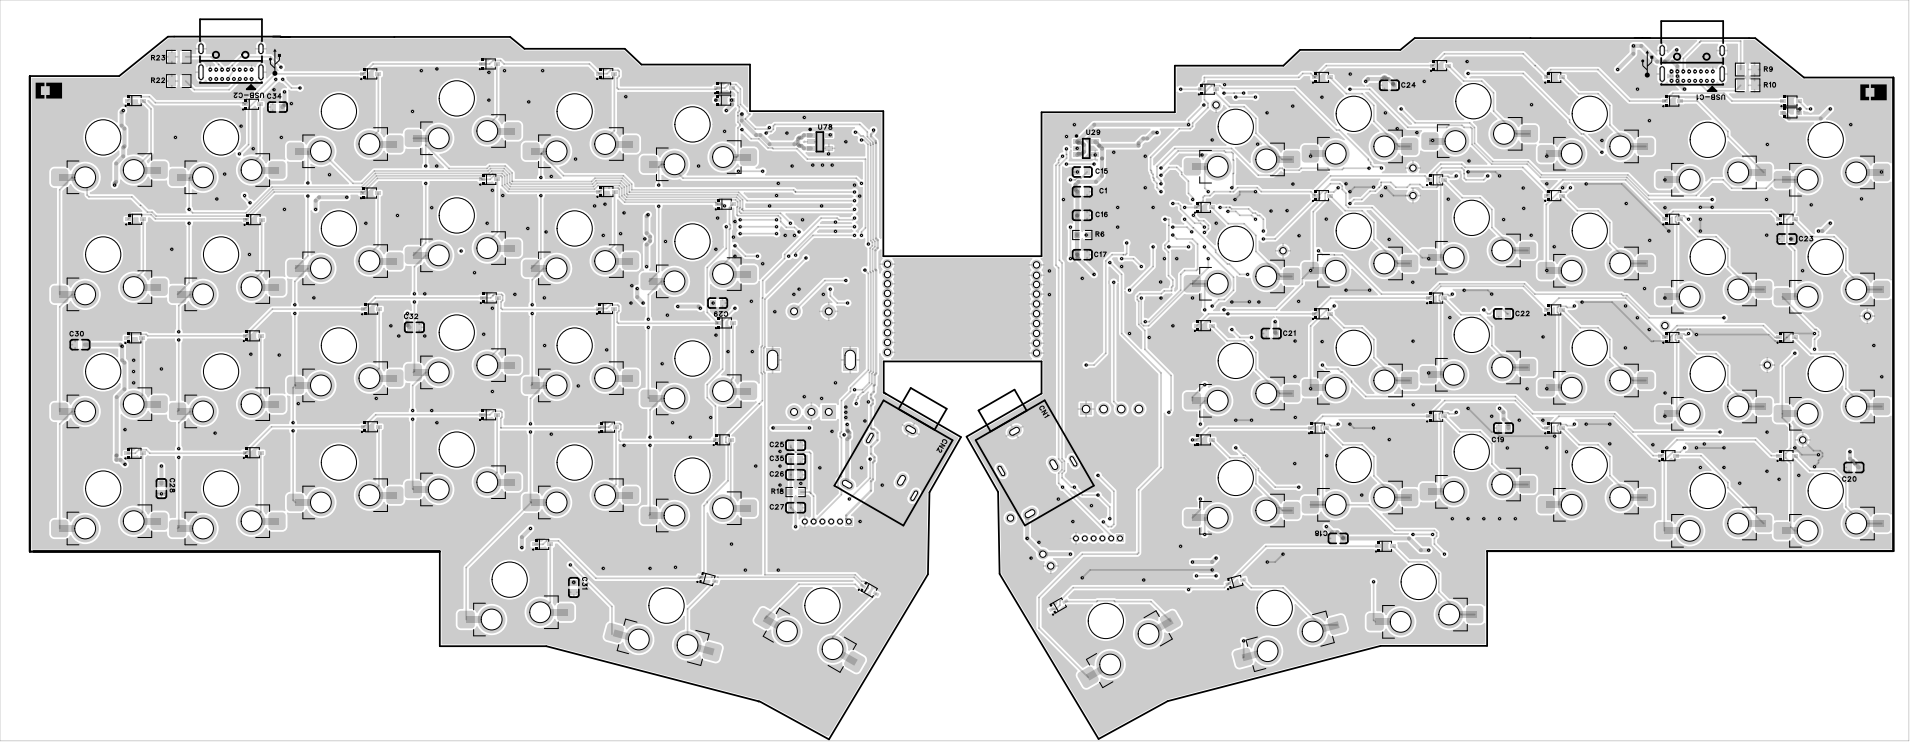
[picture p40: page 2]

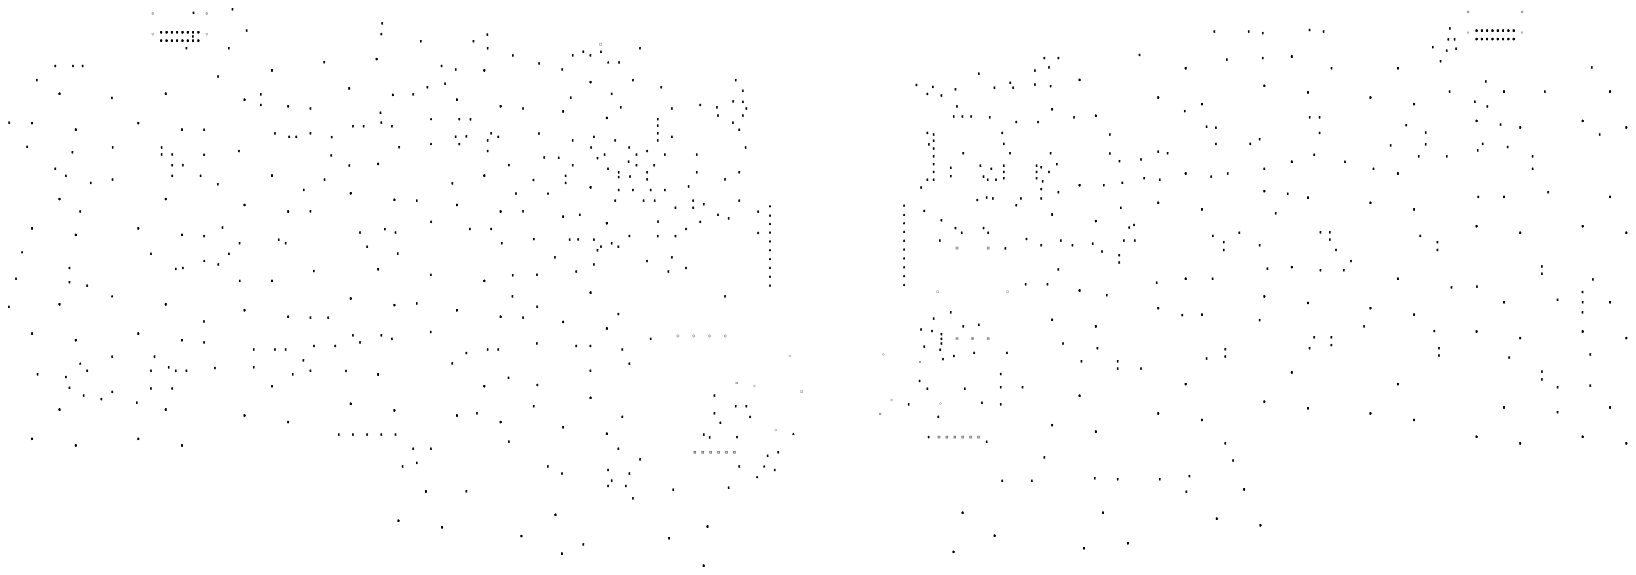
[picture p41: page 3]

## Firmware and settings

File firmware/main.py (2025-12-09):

import board
import busio
import os
import digitalio

from kb import NibunkatsuOne
from kmk.keys import KC
from kmk.modules.layers import Layers
from kmk.extensions.media_keys import MediaKeys
from kmk.extensions.rgb import RGB
from kmk.extensions.peg_oled_display import Oled, OledDisplayMode, OledReactionType, OledData

# Initialize the keyboard from our kb.py class
keyboard = NibunkatsuOne()

# --- 1. Determine Side from GPIO10 ---
# If GPIO10 is connected to GND, it's the left side; otherwise, right side
side_pin = digitalio.DigitalInOut(board.IO10)
side_pin.direction = digitalio.Direction.INPUT
side_pin.pull = digitalio.Pull.UP
is_left = not side_pin.value  # Low if connected to GND (left), high otherwise (right)

keyboard.split.split_side = SplitSide.LEFT if is_left else SplitSide.RIGHT

# --- 2. Modules & Extensions ---
keyboard.modules.append(Layers())
keyboard.extensions.append(MediaKeys())

# --- 3. RGB Setup (Under the keys) ---
rgb = RGB(
    pixel_pin=keyboard.rgb_pixel_pin,
    num_pixels=28,
    val_limit=150,     # Limit brightness (max 255) to save power
    hue_default=160,   # Cyan/Blue-ish
    sat_default=255,
    val_default=120,
    animation_speed=1,
)
keyboard.extensions.append(rgb)

# --- 4. OLED Setup (Vertical Display with Custom Graphics) ---
def render_oled(display, keyboard):
    """Custom OLED render function for vertical display"""
    # Clear display
    display.fill(0)
    
    # Get current layer name
    layer_names = ["BASE", "NUM", "NAV"]
    current_layer = layer_names[keyboard.active_layers[0]] if keyboard.active_layers else "BASE"
    
    # Display layout for vertical OLED (64x128)
    display.text("LAYER", 0, 0, 1)
    display.text(current_layer, 0, 12, 1)
    
    # Add some visual separator
    display.hline(0, 24, 64, 1)
    
    # Show keyboard info at bottom
    display.text("Nibunkatsu", 0, 100, 1)
    display.text("One", 0, 112, 1)
    
    # Optional: Show keypress indicator or other status
    # This could be expanded with more features
    
    display.show()

oled_ext = Oled(
    toDisplay=OledDisplayMode.GFX,
    oled_render=render_oled,
    flip=False,
)
keyboard.extensions.append(oled_ext)

# --- 5. Keymap ---
# Define your layers here. 
# 4 Rows x 6 Cols = 24 keys per half -> 48 keys total
# KMK maps them: [L1..L24, R1..R24]

keyboard.keymap = [
    # LAYER 0: Base (QWERTY-ish)
    [
        # --- LEFT HAND ---
        KC.TAB,  KC.Q,    KC.W,    KC.E,    KC.R,    KC.T,
        KC.LCTL, KC.A,    KC.S,    KC.D,    KC.F,    KC.G,
        KC.LSFT, KC.Z,    KC.X,    KC.C,    KC.V,    KC.B,
        KC.NO,   KC.NO,   KC.LGUI, KC.LALT, KC.MO(1), KC.SPC,

        # --- RIGHT HAND ---
        KC.Y,    KC.U,    KC.I,    KC.O,    KC.P,    KC.BSPC,
        KC.H,    KC.J,    KC.K,    KC.L,    KC.SCLN, KC.QUOT,
        KC.N,    KC.M,    KC.COMM, KC.DOT,  KC.SLSH, KC.ENT,
        KC.SPC,  KC.MO(2),KC.LEFT, KC.DOWN, KC.UP,   KC.RGHT, 
    ],
    
    # LAYER 1: Numbers (Momentary)
    [
        # Left
        KC.ESC,  KC.N1,   KC.N2,   KC.N3,   KC.N4,   KC.N5,
        KC.TRNS, KC.NO,   KC.NO,   KC.NO,   KC.NO,   KC.NO,
        KC.TRNS, KC.NO,   KC.NO,   KC.NO,   KC.NO,   KC.NO,
        KC.TRNS, KC.TRNS, KC.TRNS, KC.TRNS, KC.TRNS, KC.TRNS,

        # Right
        KC.N6,   KC.N7,   KC.N8,   KC.N9,   KC.N0,   KC.DEL,
        KC.NO,   KC.NO,   KC.NO,   KC.NO,   KC.NO,   KC.NO,
        KC.NO,   KC.NO,   KC.NO,   KC.NO,   KC.NO,   KC.NO,
        KC.TRNS, KC.TRNS, KC.TRNS, KC.TRNS, KC.TRNS, KC.TRNS, 
    ],

    # LAYER 2: Navigation / Media
    [
        # Left
        KC.TRNS, KC.NO,   KC.NO,   KC.NO,   KC.NO,   KC.NO,
        KC.TRNS, KC.NO,   KC.NO,   KC.NO,   KC.NO,   KC.NO,
        KC.TRNS, KC.NO,   KC.NO,   KC.NO,   KC.NO,   KC.NO,
        KC.TRNS, KC.TRNS, KC.TRNS, KC.TRNS, KC.TRNS, KC.TRNS,

        # Right
        KC.NO,   KC.NO,   KC.NO,   KC.NO,   KC.NO,   KC.NO,
        KC.LEFT, KC.DOWN, KC.UP,   KC.RGHT, KC.NO,   KC.NO,
        KC.MUTE, KC.VOLD, KC.VOLU, KC.NO,   KC.NO,   KC.NO,
        KC.TRNS, KC.TRNS, KC.TRNS, KC.TRNS, KC.TRNS, KC.TRNS, 
    ]
]

if __name__ == '__main__':
    keyboard.go()

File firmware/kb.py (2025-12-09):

import board
from kmk.kmk_keyboard import KMKKeyboard
from kmk.scanners import DiodeOrientation
from kmk.modules.split import Split, SplitType, SplitSide

class NibunkatsuOne(KMKKeyboard):
    def __init__(self):
        # --- Matrix Setup ---
        self.row_pins = (board.IO4, board.IO5, board.IO6, board.IO7, board.IO46)
        self.col_pins = (board.IO15, board.IO16, board.IO17, board.IO18, board.IO21, board.IO14, board.IO13)
        
        # You confirmed: Cathode to Row -> ROW2COL
        self.diode_orientation = DiodeOrientation.ROW2COL

        # --- Split Communication (TRRS) ---
        # Because you crossed the traces on the Right PCB, 
        # we use the SAME pin definitions for both chips!
        self.split = Split(
            split_type=SplitType.UART,
            data_pin=board.IO37,  # TX Pin (Tip on Left, Ring on Right)
            data_pin2=board.IO36, # RX Pin (Ring on Left, Tip on Right)
            uart_flip=True,       # Helps ESP32 negotiate the connection
            use_pio=True          # Uses dedicated hardware for stability
        )
        self.modules.append(self.split)
        
        # --- RGB Data Pin ---
        self.rgb_pixel_pin = board.IO3
        
        # --- Encoder Pins (Right Side) ---
        self.encoder_a = board.IO46
        self.encoder_b = board.IO9 

        # Call the parent init
        super().__init__()

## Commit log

2025-12-07 Added the screenshots showcasing my 4 day-long marathon of the PCB and schematics design! Uploaded the EasyEDA Project files as well!
    [Nibunkatsu_One_Rev1_3D_1.step]
2025-12-07 Added sample firmware for Nibunkatsu One keyboard. NOT TESTED!
    - Implemented keyboard firmware with matrix setup, split communication, RGB setup, and encoder pins.
    - Developed main firmware logic to initialize the keyboard, handle side detection, and set up layers, media keys, RGB, and OLED display.
    - Defined keymap for three layers: Base, Numbers, and Navigation/Media.
    [plate-2025-12-07T15_16_46.762Z.dxf]
2025-12-08 Uploaded 3D models for the case! Updated the README and JOURNAL.
    [Nibunkatsu_One_Rev1_LEFT.3mf, Nibunkatsu_One_Rev1_LEFT.step, Nibunkatsu_One_Rev1_RIGHT.3mf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]
2025-12-11 Added more assets, and renewed 3D CAD files. Added Display UI mockups.
    [44a5c62668f48c37c8519f21a4041e7cfe13850c_switch.dxf, Nibunkatsu_One_CASE_LEFT.3mf, Nibunkatsu_One_CASE_RIGHT.3mf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]
2025-12-11 Some repository rearrangements and cleanup.
    [44a5c62668f48c37c8519f21a4041e7cfe13850c_switch.dxf, Nibunkatsu_One_Rev1_3D_1.step, Nibunkatsu_One_Rev1_LEFT.3mf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]
2025-12-11 Uploaded the bom file
    [bom.csv]
2025-12-11 Updated the BOM file.
    [bom.csv]
2025-12-11 Reorganized the BOM
    [bom.csv]
2025-12-11 Update README with simplified bill of materials
    Added a simplified bill of materials (BOM) with component breakdown and projected costs.
2025-12-11 Added a README file for the PCB folder.
2025-12-11 Added 3D model obj converted from the 3mf. Updated the BOM with a better TRRS cable. Fixed confusing naming in PCB 3D exports. Enhanced Licensing explanation in the README.
    [Nibunkatsu_One_CASE_LEFT.obj, Nibunkatsu_One_CASE_RIGHT.obj, Nibunkatsu_One_PLATE_LEFT.obj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]
2025-12-11 Added another display mockup image. Updated the BOM to include shipping costs.
    [bom.csv]
2025-12-13 Updated the PCB shipping to the cheapest option!
    [bom.csv]
2025-12-13 Fix total estimated cost in README
    Updated total estimated cost in the Bill of Materials section.
